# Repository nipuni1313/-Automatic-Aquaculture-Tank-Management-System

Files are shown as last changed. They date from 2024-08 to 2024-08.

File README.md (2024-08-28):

# Automated Aquaculture Tank Monitoring System

**Department of Electronic & Telecommunication Engineering, University of Moratuwa, Sri Lanka**  
**Authors:**  
H. M. G. N. I. Herath - 210216F  
H. M. V. Vidumini - 210669U  
**Module:** EN 2160 Electronic Design Realization  
**Submission Date:** 21st July 2024

## Overview

The Automated Aquaculture Tank Monitoring System is designed to provide real-time monitoring and management of crucial parameters in aquaculture environments. The system tracks pH levels, temperature, and total dissolved solids (TDS) in fish tanks and pools, ensuring optimal conditions for fish health and growth. Additionally, it features an integrated feeder system to automate the feeding process.

This project aims to contribute to the sustainability and efficiency of the aquaculture industry by offering a comprehensive solution that enhances productivity, improves operational efficiency, and safeguards fish health.

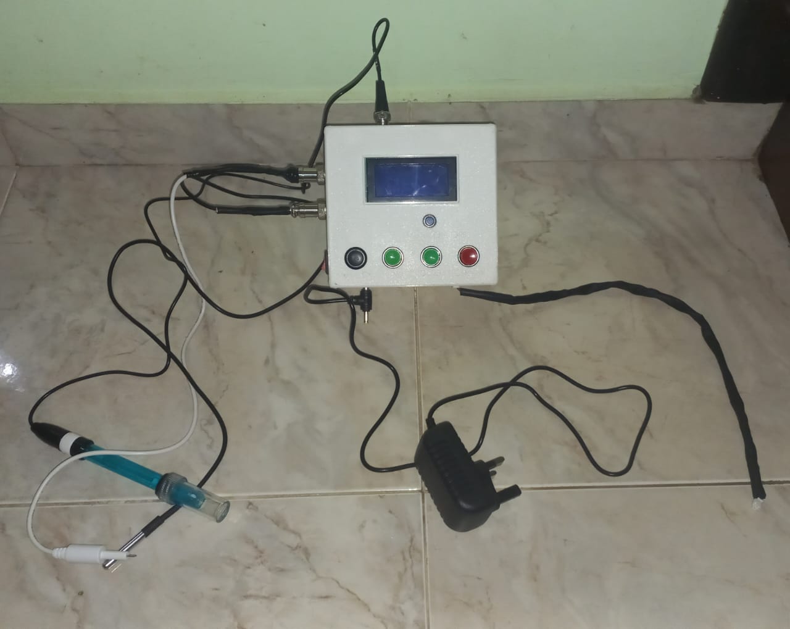
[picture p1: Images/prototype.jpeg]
Prototype of the user interface

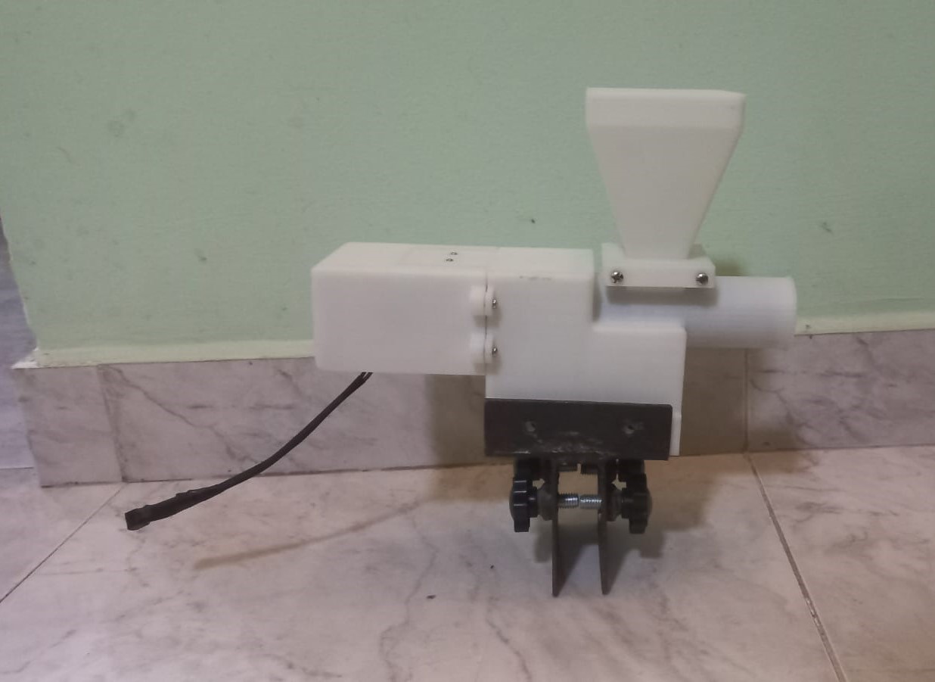
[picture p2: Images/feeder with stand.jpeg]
Prototype of the feeder


## Table of Contents

1. [General Specifications](#general-specifications)
2. [Project Objectives](#project-objectives)
3. [System Components](#system-components)
4. [Hardware Requirements](#hardware-requirements)
5. [Software Requirements](#software-requirements)
6. [Installation and Setup](#installation-and-setup)
7. [Usage](#usage)
8. [Contributing](#contributing)
9. [Acknowledgements](#acknowledgements)

## General Specifications

The project follows the Cambridge EDC model, which is structured into three main phases:

- **Explore:** Examination of existing products and stakeholder engagement to gather insights.
- **Create:** Development of conceptual designs based on identified needs.
- **Evaluate:** Assessment and refinement of designs to ensure they meet objectives and improve upon current market offerings.

## Project Objectives

- **Ensure Fish Health:** Continuous monitoring of pH, temperature, and TDS levels to maintain optimal conditions for fish well-being.
- **Improve Efficiency:** Automate monitoring and feeding processes to reduce labor and improve operational efficiency.
- **Enhance Productivity:** Provide actionable insights for optimizing farm management practices.

## System Components

The system comprises several key components:

- **Sensors:** For monitoring pH levels, temperature, and TDS.
- **Control Unit:** Manages data from sensors and controls the feeder.
- **Feeder System:** Automatically dispenses feed based on predefined schedules.
- **User Interface:** Displays real-time data and allows user interaction.

## Hardware Requirements

- Microcontroller (e.g., ATmega328P)
- pH sensor
- Temperature sensor
- TDS sensor
- LCD Display (with I2C module)
- DC Motor (for feeder system)
- Real-Time Clock (RTC) module (e.g., DS1302)
- Buzzer
- Additional connectors, resistors, capacitors, and other electronic components

## Software Requirements

- Arduino IDE for microcontroller programming
- Relevant libraries for sensor integration (e.g., LiquidCrystal_I2C for LCD, RTClib for RTC)
- Python or another language for data analysis (if needed)

## Installation and Setup

**Hardware Setup:**

- Assemble the hardware components according to the schematic diagrams provided in the project documentation.
- Connect the sensors to the microcontroller using appropriate connectors.

**Software Setup:**

- Download and install the Arduino IDE.
- Install necessary libraries (LiquidCrystal_I2C, RTClib, etc.).
- Upload the provided code to the microcontroller using the Arduino IDE.

## Usage

- Once the system is powered on, it will automatically begin monitoring the tank conditions.
- Real-time data will be displayed on the LCD screen.
- Alerts will be triggered if any parameter exceeds the predefined threshold.
- The feeder system can be scheduled to dispense feed automatically at set intervals.

## Contributing

Contributions are welcome! Please feel free to submit a pull request or open an issue to discuss any changes or improvements.

## Acknowledgements

We would like to acknowledge the support of the Department of Electronic & Telecommunication Engineering, University of Moratuwa, Sri Lanka.

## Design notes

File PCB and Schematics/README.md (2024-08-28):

This contains all the dacuments related to the PCB and its schematics.

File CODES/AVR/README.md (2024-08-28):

# AVR Code for Aqua Culture Fish Feeder System

This directory contains the AVR code for the Aqua Culture Fish Feeder System, which monitors and controls environmental parameters in an aquaculture tank using an ATmega328P microcontroller. The code includes functionality for an LCD display, sensor readings for temperature, pH, and TDS (Total Dissolved Solids), motor control for fish feeding, and a button-based menu system.

## Features

- **LCD Display Control**: Utilizes an I2C 16x2 LCD to display sensor readings and system status.
- **Temperature Sensing**: Interfaces with a DS18B20 sensor to monitor water temperature.
- **TDS and pH Monitoring**: Reads and displays water quality using analog TDS and pH sensors.
- **Motor Control**: Operates a feeding motor based on user settings and schedules.
- **User Interface**: Provides a simple button-driven menu for setting parameters and manual control.

## File Overview

- **main.c**: The main application code that initializes all peripherals and manages the main program loop.
- **Functions for LCD**: Functions and definitions for controlling the I2C LCD display.
- **ds18b20**: Functions for interfacing with the DS18B20 temperature sensor.
- **tds & pH**: Code for reading TDS and pH sensor values.
- **motor control**: Functions for controlling the feeding motor.
- **menu**: Implements the user interface for navigating the menu and setting parameters.

## Installation

To compile and upload the AVR code to the ATmega328P microcontroller:

1. **Clone this repository**:
    ```bash
    git clone https://github.com/yourusername/aqua-culture-fish-feeder.git
    cd aqua-culture-fish-feeder/avr_code
    ```

2. **Open in AVR Development Environment**:
   - You can use Atmel Studio, Arduino IDE, or any AVR-compatible IDE.
   
3. **Compile the Code**:
   - Ensure all necessary libraries and header files are included.
   - Set the microcontroller to ATmega328P and the correct clock speed (e.g., 16 MHz).

4. **Upload the Code**:
   - Connect your ATmega328P microcontroller to your computer via an AVR programmer or Arduino board.
   - Upload the compiled code to the microcontroller.

## Usage

1. **Power on the system** and observe the initialization messages on the LCD display.
2. **Navigate the menu** using the connected buttons to configure settings such as feeding times and sensor thresholds.
3. **Monitor the sensors**: Temperature, pH, and TDS readings will be continuously displayed on the LCD.
4. **Control the motor**: Use the menu to manually activate the feeding motor or set automated feeding schedules.

## Contributing

Feel free to contribute to the project by forking the repository, making changes, and submitting a pull request. For significant changes, please open an issue first to discuss your ideas.

## License

This code is open-source and available under the MIT License. See the [LICENSE](LICENSE) file for more information.

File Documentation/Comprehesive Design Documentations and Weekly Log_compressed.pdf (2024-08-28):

## Department of Electronic & Telecommunication Engineering, University

of Moratuwa, Sri Lanka.

# Automated Aquaculture Tank Monitoring System Design Documentation

H. M. G. N. I. Herath | 210216F
H. M. V. Vidumini | 210669U

## Submitted in partial fulfillment of the requirements for the module EN 2160 Electronic Design Realization

21st July 2024

## Contents

1 Comprehensive Design Details | 3
1.8.2 | Final Artwork Drawings
2 Appendix A : Weekly Log Entries | 107

EN 2160 Electronics Design Realization

2.5 4 March - 10 March 2024 | 108
2.6 11 March - 17 March 2024 | 109
2.7 18 March - 24 March 2024 | 110
2.8 25 March - 31 March 2024 | 111
2.9 1 April - 7 April 2024 | 113
2.10 15 April - 21 April 2024 | 116
2.11 22 April - 28 April 2024 | 118
2.12 29 April - 5 May 2024 | 118
2.13 6 May - 12 May 2024 | 120
2.14 6 May - 12 May 2024 | 121
2.15 June 21 - June 27 2024 | 122
2.16 June 28- July 6 2024 | 122
2.17 July 16 - July 22 2024 | 123
3 Appendix B : Previously Used Arduino Code | 124

## 1 Comprehensive Design Details

### 1.1 Introduction

This report presents a comprehensive analysis and design documentation for an advanced aquaculture monitoring and feeding system. The system integrates various sensors and electronic components to ensure optimal water quality and automate feeding processes in aquaculture environments. The aim is to provide a reliable, durable, and user-friendly solution that enhances the efficiency and effectiveness of fish tank management.

### 1.2 Project overview

Our project involves the design and development of an advanced aquaculture monitoring and feeding system. The system is engineered to provide real-time monitoring of crucial water parameters and automate the feeding process in fish tanks, thereby enhancing the efficiency and health management of aquaculture environments.

### 1.3 The primary objectives of the aquaculture tank monitoring device

The primary objectives of the device are:

- Real-time Monitoring: Provide continuous and accurate monitoring of pH, Total Dissolved Solids (TDS), and water temperature in fish tanks.
- Alert System: Notify users promptly through alarms and warning messages when monitored parameters fall outside specified ranges.
- User Interface: Offer an intuitive interface with LCD display and pushbuttons for easy navigation and parameter adjustment.
- Feeding Automation: Automate fish feeding schedules based on user-defined times or allow manual feeding control through the interface.
- Durability and Reliability: Ensure robust construction using materials like ABS plastic and metal stands to withstand aquatic environments.
- Ease of Installation: Facilitate simple installation on tank rims using hooks and adjustable screws, ensuring stability and optimal sensor placement.
- Enhanced Aquaculture Management: Support efficient and effective management of fish tanks to promote healthier aquatic environments and growth.

These objectives aim to enhance user experience, streamline aquarium maintenance, and contribute to the overall well-being of aquatic life through advanced monitoring and feeding automation capabilities.

### 1.4 Sensor Specifications

In our aquaculture tank monitoring system, accurate and reliable data collection is critical for maintaining optimal water quality conditions. The system uses 3 sensors to monitor the key parameters
- pH
- Total Dissolved Solids (TDS)
- water temperature

This section provides detailed specifications of the sensors integrated into the system. Each sensor is chosen for its precision, reliability, and suitability for continuous monitoring in an aquaculture environment.

### 1.4.1 pH Sensor

The pH level of water is a crucial parameter in aquaculture as it directly affects the health and growth of aquatic organisms. Maintaining an optimal pH range is essential for ensuring the metabolic processes of fish and other aquatic life are functioning properly. Deviations from the ideal pH range can lead to stress, disease, and even mortality. Therefore, monitoring pH levels continuously helps in maintaining a stable and healthy environment, improving the overall productivity and sustainability of the aquaculture operation.
The chosen sensor and its specifications are as follows:

Figure 1: pH Sensor E-201-C

Model: pH Sensor E-201-C
- Measurement Range: 0 - 14 pH
- Accuracy: ±0.01 pH
- Resolution: 0.01 pH
- Operating Temperature: 0°C to 50°C
- Response Time: ¡= 10 seconds for 95% of final value
- Output Type: Analog Voltage
- Supply Voltage: 3.3V to 5V
- Calibration: Two-point (4.0, 7.0, and 10.0 pH)
- Connector: BNC connector for pH probe

### 1.4.2 TDS Sensor

Total Dissolved Solids (TDS) measure the combined content of all inorganic and organic substances contained in a liquid, which are present in a molecular, ionized, or micro-granular suspended form. In aquaculture, maintaining appropriate TDS levels is essential for the health of aquatic organisms as it affects water hardness, salinity, and the overall ionic balance. High TDS levels can indicate poor water quality and the presence of harmful substances, whereas low levels can lead to nutrient deficiencies. Continuous monitoring of TDS helps in maintaining optimal water quality and preventing potential health issues in the aquaculture environment.
The chosen sensor and its specifications are as follows:

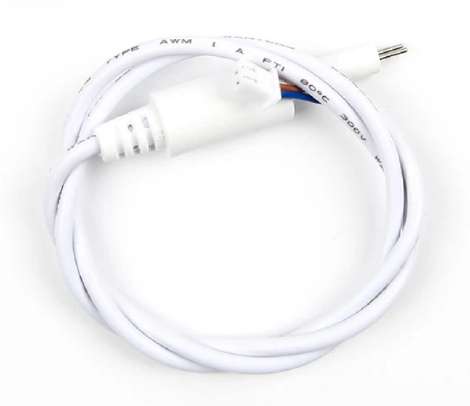
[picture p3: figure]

Figure 2: Gravity TDS Meter V1.0

Model: Gravity TDS Meter V1.0

- Measurement Range: 0 - 1000 ppm
- Accuracy: ±10% full scale
- Resolution: 1 ppm
- Operating Temperature: 0°C to 40°C
- Response Time: 10 seconds
- Output Type: Analog Voltage
- Supply Voltage: 3.3V to 5V
- Calibration: One-point (700 ppm)
- Connector: 3-pin JST connector

### 1.4.3 Water Temperature Sensor

Water temperature is a critical factor in aquaculture as it influences the metabolic rates, growth, and reproductive cycles of aquatic organisms. Each species has a preferred temperature range, and deviations from this range can cause stress, reduce immune response, and impact overall health. Additionally, temperature affects the solubility of oxygen and the efficacy of other water quality parameters. Continuous temperature monitoring allows for the maintenance of optimal conditions, ensuring a healthy and productive aquaculture environment.
The chosen sensor and its specifications are as follows:

Figure 3: DS18B20 Digital Thermometer

Model: DS18B20 Digital Thermometer

- Measurement Range: -55°C to +125°C
- Accuracy: ±0.5°C (from -10°C to +85°C)
- Resolution: Programmable 9 to 12 bits
- Response Time: ¡= 750 milliseconds
- Output Type: Digital (1-Wire Protocol)
- Supply Voltage: 3.0V to 5.5V
- Connector: 3-pin (VCC, GND, Data)

### 1.5 Microcontroller specifications

The Atmel® picoPower® ATmega328P microcontroller is an excellent choice for this project due to its low-power CMOS architecture and high performance. This 8-bit microcontroller, based on the AVR® enhanced RISC architecture, executes powerful instructions in a single clock cycle, achieving throughputs close to 1MIPS per MHz. This allows for optimization between power consumption and processing speed, making it ideal for sensor applications.
The below is a summary of key features which are extracted from ATMega328P datasheet. (https://ww1.microchip.com/downloads/en/DeviceDoc/Atmel-7810-Automotive-Microcontrollers-ATmega328P_Datasheet.pdf)

Key Features

- Advanced RISC Architecture:

– 131 powerful instructions, mostly single clock cycle execution.

– Up to 20 MIPS throughput at 20MHz.

- Memory:

– 32KB In-System Self-Programmable Flash memory.

– 1KB EEPROM.

– 2KB SRAM.

- Peripheral Features:

– 8-channel 10-bit ADC.

– Six PWM channels.
– Two 8-bit Timer/Counters and one 16-bit Timer/Counter.

– Master/Slave SPI Serial Interface.

– I2C compatible 2-wire Serial Interface.

- Power Consumption:

– Active Mode: 0.2mA at 1MHz, 1.8V.

– Power-down Mode: 0.1µA.
– Power-save Mode: 0.75µA (including 32kHz RTC).
- Operating Voltage:

– 1.8 - 5.5V.

- Operating Temperature Range:

– -40°C to 105°C.

### 1.6 Circuit Analysis for Electronic Sub-Assemblies

The electronic design for our comprehensive monitoring and management system consists of 7 main electronic sub-assemblies. These sub-assemblies work together to monitor and maintain optimal conditions in fish tanks and pools used in both ornamental fish breeding and fish farming for human consumption. The sub-assemblies include,

1. Power Regulator
2. Microcontroller Unit
3. pH Sensor Module and Interface
4. Water Temperature Sensor Module and Interface
5. TDS Sensor Module and Interface
6. User Interface
7. Motor Drive and Switch

Each sub-assembly plays a critical role in ensuring the system’s functionality and reliability. This document provides detailed descriptions of each sub-assembly, including their specifications, components, and functionality within the system.

### 1.6.1 Power Regulator

The power regulator converts the input voltage from 12V to a stable 5V using the LM7805CT power regulator.

Figure 4: Voltage Regulator Circuit

Components and Sections

1. Power Input: The 12V DC input is connected to the circuit via the input connector J1.
2. Input Filtering: Capacitor C1, connected across the input voltage, filters out any noise or spikes from the input power supply. This ensures that the voltage regulator receives a clean 12V DC input.
3. Voltage Regulation: The LM7805CT voltage regulator receives the filtered 12V input at its IN pin (Pin 1). It regulates this input down to a stable 5V DC, which is provided at its OUT pin (Pin 3). The ground pin (Pin 2) is connected to the common ground of the circuit.

4. Output Filtering: Capacitor C2, connected across the output voltage, smooths out any residual noise or ripple in the 5V output, providing a clean and stable 5V DC to the load.

In summary, the power regulator sub-assembly is designed to take a 12V DC input and provide a stable 5V DC output using an LM7805CT voltage regulator. The capacitors (C1 and C2) are crucial for filtering and stabilizing the input and output voltages, respectively. Therefore, this ensures that all components in the system receive a consistent and reliable power supply, which is essential for their optimal operation. The microcontroller unit serves as the brain of the system, orchestrating various tasks through its sub-units: power supply filtering, oscillator circuit, in-system programming, reset circuit, and peripheral I/O connections. Each sub-unit plays a critical role in ensuring the functionality and stability of the system.

### 1.6.2 Microcontroller Unit

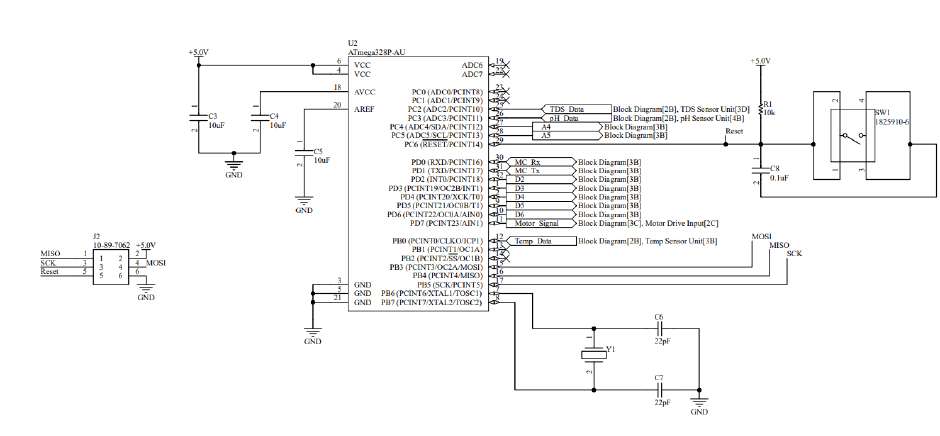
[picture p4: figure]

Figure 5: Microcontroller Unit Circuit

1. Power Supply Filtering
- Components: C3, C4, C5 (10µF Capacitors)
- Function: These capacitors filter the 5V power supply to provide a stable voltage to the microcontroller and other connected components, minimizing voltage fluctuations and noise.

Components and Sections

2. In-System Programming (ISP)
- Component: J2 (Programming Header)
- Function: This header is used for programming the microcontroller via ISP, allowing firmware updates and debugging without removing the microcontroller from the circuit.
3. Oscillator Circuit
- Components: Y1 (Crystal Oscillator), C6, C7 (22pF Capacitors)
- Function: The crystal oscillator (Y1) provides the clock signal necessary for the microcontroller’s operations. The capacitors (C6 and C7) stabilize the oscillations of the crystal, ensuring accurate and reliable timing.
4. Reset Circuit
- Components: R1 (10k Resistor), C8 (0.1µF Capacitor), SW1 (Reset Switch)
- Function:

– R1: The pull-up resistor keeps the reset pin high under normal conditions.
– C8: The capacitor debounces the reset switch to prevent false triggering.
– SW1: The reset switch allows for manually resetting the microcontroller, reinitializing the system as needed.
5. Peripheral Connections
- Analog and Digital I/O Pins:

– ADC6, ADC7 (Pins 18, 20): Used for receiving data from the TDS and pH sensors. – Digital Pins (PC0 - PC6, PD0 - PD7, PB0 - PB7): Connected to various sensors, the motor driver, and user interface elements, facilitating communication and control.

- Serial Communication Pins:

– TX, RX (PD0, PD1): These pins are designated for serial communication, enabling data exchange with other devices.
– SPI (PB3 - PB5): These pins are used for in-system programming and communication with other SPI devices, supporting data transfer and device interfacing.

The microcontroller unit is integral to the system’s operation, coordinating tasks through wellstructured sub-units. These include power supply filtering for voltage stability, an oscillator circuit for precise timing, ISP for easy programming, a reset circuit for system reinitialization, and various peripheral connections for interfacing with sensors and other components.

### 1.6.3 pH Sensor Module and Interface

The pH sensor module interfaces with the pH sensor to obtain pH readings, process the signal, and transmit it to the microcontroller. This module includes operational amplifiers (op-amps), voltage references, and other necessary components for measuring and processing pH levels from a pH sensor.

Figure 6: pH sensor module

Components and Functions

1. pH Sensor Input
- Function: Connects the pH sensor to the module, allowing the analog signal proportional to the pH level to be processed.
- Component: Connector (J7)
2. Signal Conditioning
- Function: Buffers and stabilizes the pH signal from the sensor to isolate it from the rest of the circuit.
- Components:

– Op-Amp: U4A (TLC4502IDR) – Resistors: R14, R15, R16
– Capacitors: C13, C14, C15
3. Signal Amplification
- Function: Amplifies the buffered pH signal to a level suitable for further processing.
- Components:

– Op-Amp: U3B (LM358DR)
– Resistors: R17, R18
– Capacitors: C16, C17
4. Voltage Reference
- Function: Provides a stable reference voltage for the op-amps to ensure accurate measurements.

- Components:

– Voltage Reference: U1 (TL431ACZ-AP) – Resistors: R19, R20
– Capacitors: C18, C19
5. Output Signal Conditioning
- Function: Further conditions the amplified signal, making it suitable for the ADC in the microcontroller.
- Components:

– Op-Amp: U5A (LM358DR)
– Resistors: R22, R23, R24 – Capacitors: C19
– Diodes: D1, D2
6. Temperature Compensation
- Function: Compensates the pH signal for temperature variations to ensure accuracy across different temperatures.
- Components:

– Thermistor: TH1 (NTCLE100E3104JB0)
– Op-Amp: U3A (LM358DR)
– Resistors: R21, R22, R23, R24
– Capacitors: C19
7. Backup Connector
- Function: Provides the conditioned pH signal to the microcontroller for further processing and analysis.
- Components:

– Connector: J2
– Op-Amp: U5B (LM358DR)

This pH sensor module is designed to interface a pH sensor with a microcontroller. It conditions the analog signal from the pH sensor, amplifies it, compensates for temperature variations, and provides a stable, noise-free output signal to the microcontroller. The use of op-amps, voltage references, and passive components ensures accurate and reliable pH measurements.

### 1.6.4 Water Temperature Sensor Module and Interface

The digital water temperature connected to the device operates using the sub-assembly given below.

Figure 7: Water Temperature Sensor Module

Functionality: This module interfaces a temperature sensor with a microcontroller, providing the necessary power and signal conditioning to ensure accurate temperature data is communicated to the microcontroller.
Components:

- Connector: J9 - B3B-XH-AM(LF)(SN)(P)
- Pull-up Resistor: R47
- Temperature Data Line: Temp Data

### 1.6.5 TDS Sensor Module and Interface

Figure 8: TDS Sensor module

TDS Sensor Module and Interface provides an interface to the TDS sensor to connect with the microcontroller. It includes various operational amplifiers (op-amps), voltage regulators, and other components necessary for measuring and processing TDS levels from a TDS sensor.

Components and Sections

1. Power Supply
Functionality: Provides stable voltage supply to various parts of the circuit.

Components:

- Voltage Regulators:

– AMS1117-3.3 (U8): Regulates the input 5V to a stable 3.3V output.
– TPS60400DBVR (U9): Provides a negative voltage (-3V) from a positive 3.3V input.
- Capacitors:

– C28, C29, C30: Decoupling capacitors for U8.
– C31, C32, C33, C34, C35, C36, C37: Charge pumping and output stabilization capacitors for U9.
2. TDS Sensor Input
Functionality: Receives the input signal from the TDS sensor. Components:
- Connectors

– J8: Primary input for the TDS sensor.
– J21: Secondary connection point, for calibration of the sensor and backup purposes.
3. Signal Conditioning

Functionality: Buffers and amplifies the input signal from the TDS sensor.

Components:

- Op-Amp (U6A - LMV324IDR): Buffers and amplifies the TDS sensor signal.
- Resistors:

– R39, R40, R41, R42: Set gain and biasing for U6A.
- Capacitors:

– C20, C21, C22, C23: Decoupling and noise reduction.
- Voltage Reference (U7 - CJ4006DM): Provides a stable reference voltage.
- Resistors:

– R43, R44, R45, R46: Set output voltage for U7.
- Capacitors:

– C24, C25, C26, C27: Stabilize the reference voltage.

4. Signal Amplification

Functionality: Further amplifies and conditions the TDS signal.

Components:

- Op-Amps (U6B, U6C, U6D - LMV324DR): Amplify and condition the TDS signal.
- Resistors:

– R34, R35, R36, R37, R38, R47, R48, R49, R50: Set gain and biasing for amplification stages.
- Capacitors:

– C19, C38, C39, C40, C41, C42, C43, C44: Filtering and decoupling.
- Diodes:

– D1, D2, D3, D4, D5, D6: Protect op-amps from voltage spikes.

5. Output Signal Conditioning

Functionality: Buffers the final TDS signal before sending it to the microcontroller.

Components:

- Op-Amp (U6D - LMV324DR): Buffers the final TDS signal.
- Resistors:

– R60, R61: Set output level and feedback.
- Capacitor:

– C25: Stabilizes the output signal.

6. Output to Microcontroller

Functionality: Provides the conditioned TDS signal to the microcontroller for further processing.

Components:

- Connector (J21): Delivers the TDS Data signal to the microcontroller.

This circuit is designed to interface a TDS sensor with a microcontroller. It conditions the analog signal from the TDS sensor, amplifies it, and provides a stable, noise-free output signal to the microcontroller. The use of op-amps, voltage regulators, and passive components ensures accurate and reliable TDS measurements. The negative voltage generator and multiple stages of amplification and filtering are crucial for achieving high precision in TDS readings.

### 1.6.6 User Interface

The user interface circuit interfaces the buttons, display, and the WiFi module to the microcontroller, allowing for user interaction and connectivity. It includes connectors and necessary components for stable and reliable operation.

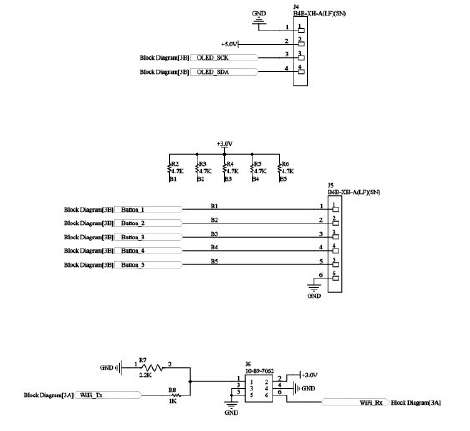
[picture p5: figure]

Figure 9: User Interface

Functionality and Components

1. Display: The display module connects through the J4 connector, allowing the microcontroller to send data and commands for visual output.
- Connector (J4):

– Provides the interface for the display module to connect to the circuit.
– Ensures proper data and power connections between the microcontroller and the display.
2. Buttons Panel: The buttons connect through the J5 connector. When a button is pressed, the corresponding input signal changes state, which is detected by the microcontroller.
The pull-up resistors (R2, R3, R4, R5, R6) ensure stable input signals and reduce noise.
- Connector (J5):

– Provides the interface for the buttons panel to connect to the circuit.
- Resistors (R2, R3, R4, R5, R6):

– Pull-up resistors ensure that each button input is at a known voltage level when not pressed.
– Provides debounce functionality to avoid multiple triggers from a single button press.
3. WiFi Module Interface: The WiFi module connects through the J6 connector, enabling wireless communication.
Resistor R7 ensures the signals between the microcontroller and the WiFi module are stable and within proper voltage levels.
- Connector (J6):

– Provides the interface for the WiFi module to connect to the circuit.
- Resistor (R7):

– Ensures the proper biasing and signal integrity for the WiFi module interface.

Additionally, it should be mentioned that the buzzer for the alarm system which is also a part of the user interface is to be connected to pin 12, after the microcontroller is programmed.

This user interface circuit facilitates the interaction between the user and the system via buttons and display, and enables wireless communication through the WiFi module. The use of connectors and resistors ensures stable and reliable connections and signal integrity.

### 1.6.7 Motor Drive and Switch

The motor driver part controlls the motor mechanism and provides and interface to the motor in the feeder.

Figure 10: Motor Drive and switch

Components and Connections

1. MOSFET (Q1 - IRF540N):
- Function: Acts as a switch to control the motor. The gate of the MOSFET receives the control signal (Motor Signal), which determines whether the MOSFET is on or off.
- Gate Resistor (R48 - 100 ohms): Limits the inrush current to the gate to protect the MOSFET and control the switching speed.
- Pull-down Resistor (R49 - 10k ohms): Ensures that the MOSFET stays off when there is no input signal, preventing accidental activation.
2. Diode (D9 - 1N5819):
- Function: Provides a path for the current when the motor is turned off, protecting the MOSFET from voltage spikes caused by the inductive load (motor).
- Protection: Ensures the longevity of the MOSFET by preventing back EMF from damaging it.
3. Connector (J10):
- Function: Connects the motor to the circuit.
- Pin 1: Connected to the drain of the MOSFET.
- Pin 2: Connected to the +12V supply.
4. Capacitor (C38 - 100uF):
- Function: Provides decoupling and helps to smooth out voltage fluctuations and noise from the power supply.
- Stabilization: Ensures stable operation of the motor by reducing voltage spikes and ripples.

5. Control Signal (Motor Signal):
- Source: Comes from the microcontroller unit (MCU) and is applied to the gate of the MOSFET through the gate resistor.
- Function: Determines the on/off state of the MOSFET, thereby controlling the motor.

Operation

- When Motor Signal is High:

– The gate of the MOSFET (Q1) receives a high signal, turning the MOSFET on.

– Current flows from the +12V supply through the motor (connected to J10), the MOSFET, and to ground, powering the motor.

- When Motor Signal is Low:

– The gate of the MOSFET (Q1) receives a low signal, turning the MOSFET off.

– No current flows through the motor, thus turning it off.

- Protection Mechanism:

– The diode (D9) protects against voltage spikes by providing a path for the inductive kickback current.
– The capacitor (C38) stabilizes the supply voltage, ensuring smooth operation of the motor.

In conclusion, this motor drive circuit utilizes a MOSFET (IRF540N) to control a motor using a digital signal (Motor Signal) from a microcontroller. The design includes protective components such as a diode to prevent voltage spikes and a capacitor to smooth power supply fluctuations. This simple yet effective circuit ensures reliable motor control and protection of the components.

### 1.7 PCB Specifications

### 1.7.1 Trace Width Calculations

Trace width is a crucial parameter in PCB design, influencing the board’s electrical performance and thermal management. Proper trace width ensures that the traces can handle the expected current without excessive heating or voltage drop, thereby maintaining the reliability and functionality of the PCB.

Calculation Methodology:

The trace width for different nets in a PCB is calculated based on the maximum current the trace needs to carry, the permissible temperature rise, and the PCB material properties. The IPC-2221 standard provides guidelines for determining the appropriate trace width for given current and temperature rise requirements.

The formula used for calculating the trace width is derived from the IPC-2221 standards:

W =

I
k · (Tr)

0.44 · (A)

0.725

where:
- W is the trace width (in mils)
- I is the current (in amperes)
- k is a constant (0.024 for external layers, 0.048 for internal layers)
- Tr is the temperature rise (in °C)
- A is the cross-sectional area (in mils²
)

Design Requirements:

The calculations are done using these assumptions and facts:

- Ambient Temperature: 25°C
- Temperature Rise: 10°C
- Copper Thickness: 1 oz/ft²

The PCB design includes the following trace widths for different nets:

1. 55 mil for Powering the Motor
2. 15 mil for Power Traces
3. 10 mil for Signal Traces

Calculations:

1. 55 mil for Powering the Motor Considering
- a maximum trace length: 4000mil
- maximum current: 1.5A

Calculated trace width:

- maximum: 53 mil
- minimum: 18 mil

Therefore trace width of 55 mil is chosen considering other possibilities as well.

2. 15 mil for Power Traces Considering
- a maximum trace length: 9000 mil
- maximum current: 200 mA

Calculated trace width:

- maximum: 3.5 mil
- minimum: 1.5 mil

Therefore trace width of 15 mil is chosen considering other possibilities as well.

3. 10 mil for Signal Traces Considering
- a maximum trace length: 10 000 mil
- maximum current: 50 mA

Calculated trace width:

- maximum: 0.2 mil
- minimum: 0.5 mil

Therefore trace width of 10 mil is chosen considering other possibilities as well.

Using larger trace widths than strictly required by the calculated values offers several advantages in PCB design.

- Firstly, it enhances reliability by reducing resistance and thereby minimizing voltage drops, especially crucial for high-current paths like power lines to motors or critical components.
- Secondly, larger traces can handle higher currents safely without excessive heating, which extends the lifespan of the PCB and reduces the risk of thermal damage.
- Additionally, during manufacturing and assembly processes, having slightly oversized traces can simplify production by reducing the sensitivity to slight variations in fabrication tolerances or soldering quality.

Overall, while there may be a marginal increase in material cost or PCB size, the benefits in terms of reliability, longevity, and ease of manufacturing often justify using larger trace widths when feasible in electronic designs.

### 1.7.2 Power Calculations

We refered to data sheets and identified the below voltage and current requirements

- pH Sensor:

– Current drawn: 20mA

– Voltage: 5V

- Digital Temperature Sensor:

– Current drawn: 6mA

– Voltage: 5V

- TDS Sensor:

– Current drawn: 6mA

– Voltage: 5V

- Microcontroller:

– Active mode: 1.5mA

– Sleep mode: 1uA

- Wi-Fi Module:

– Active mode: 200mA

– Voltage: 3.3V

- LCD Display:

– Current drawn: 1.65mA

– Voltage: 5V

- Buzzer:

– Current drawn: 10mA

– Voltage: 5V

- DC Motor:

– Current drawn: 300mA

– Voltage: 12V

After reviewing the current requirements for each component in our system, the trace width calculations were conducted to ensure robust PCB design. The highest current draw identified was from the DC Motor at approximately 300mA. Considering a safety margin, the trace width was calculated for 450mA to account for variations and ensure reliability. Using the IPC-2221 standard and assuming 1oz copper thickness, the calculated trace width for the DC Motor was approximately 6.81 mils (0.173 mm), rounded to the nearest standard practice of 10 mils (0.254 mm) for power lines. This approach ensures adequate current carrying capacity and supports the overall reliability of the PCB design for our aquaculture monitoring system.

### 1.7.3 Design Rule Violation Report

The following table shows the design rules violation report for the PCB design. The report indicates that there are no violations, ensuring that the design adheres to all specified constraints.

Rule Violations | Count
Clearance Constraint (Gap=5mil) (All),(All) | 0
Short-Circuit Constraint (Allowed=No) (All),(All) | 0
Un-Routed Net Constraint ( (All) ) | 0
Modified Polygon (Allow modified: No), (Allow shelved: No) | 0
Width Constraint (Min=0.05mil) (Max=55mil) (Preferred=5mil) (All) | 0
Power Plane Connect Rule(Direct Con-nect )(Expansion=20mil) (Conductor Width=10mil) (Air Gap=10mil) (En-tries=4) (InPadClass(’PowerPads’)) | 0
Power Plane Connect Rule(Relief Con-nect )(Expansion=11.811mil) (Conduc-tor Width=5mil) (Air Gap=5mil) (En-tries=4) (All) | 0
Minimum Annular Ring (Mini-mum=3mil) (All) | 0
Hole Size Constraint (Min=11.811mil) (Max=248.031mil) (All) | 0
Hole To Hole Clearance (Gap=9.842mil) (All),(All) | 0
Minimum Solder Mask Sliver (Gap=0mil) (All),(All) | 0
Silk To Solder Mask (Clearance=5mil) (IsPad),(All) | 0
Silk to Silk (Clearance=0mil) (All),(All) | 0
Net Antennae (Tolerance=0mil) (All) | 0
Board Clearance Constraint (Gap=0mil) (All) | 0
Height Constraint (Min=0mil) (Max=71497.938mil) (Preferred=500mil) (All) | 0
Total | 0

Table 1: Design Rules Violation Report

### 1.8 PCB Design

The documents containing layout and artwork for the PCB are as follows:

1.8.1 3D Views
Sub Topic Number | Figure Number | Caption | Page
1 | Figure 11 | 3D view - Top Layer | 23
2 | Figure 12 | 3D view - Bottom Layer | 24

Table 2: 3D Views

### 1.8.2 Final Artwork Drawings

Sub Topic Number | Figure Number | Caption | Page
1 | Figure 13 | Top-Layer | 25
2 | Figure 14 | Bottom Layer | 26
3 | Figure 15 | Top Silkscreen Overlay | 27
4 | Figure 16 | Mechanical Drawing | 28
5 | Figure 17 | Top Designator | 29
6 | Figure 18 | Top Assembly | 30
7 | Figure 19 | Top Component Outline | 31
8 | Figure 20 | Top 3D Body | 32
9 | Figure 21 | Top Courtyard | 33
10 | Figure 22 | Top Component Centre | 34
11 | Figure 23 | Top Pad Master | 35
12 | Figure 24 | Bottom Pad Master | 36
13 | Figure 25 | Drill Drawing for Top-Bottom Layer | 37
14 | Figure 26 | Drill Guide for Top-Bottom Layer | 38

Table 3: Final Artwork Drawings

### 1.8.3 Gerber Files

Sub Topic Number | Figure Number | Caption | Page
1 | Figure 27 | Copper Signal Bottom/Top | 39
2 | Figure 28 | Legend Top | 40
4 | Figure 29 | Paste Top | 40
5 | Figure 30 | Profile | 41
7 | Figure 32 | Soldermask Top/Bottom | 42

Table 4: Gerber Files

1.8.1 3D Views

The 3D views provides a three-dimensional visualization of the bottom side of the PCB with all its components. This view allows for a thorough inspection of the bottom side, checking the placement and orientation of components, and ensuring proper clearance and fit. Like the top view, it is also valuable for confirming the design and for presentations. These are crucial for visualizing the final product before manufacturing, helping to identify any potential issues in component placement or board design.

Figure 11: 3D view - Top Layer

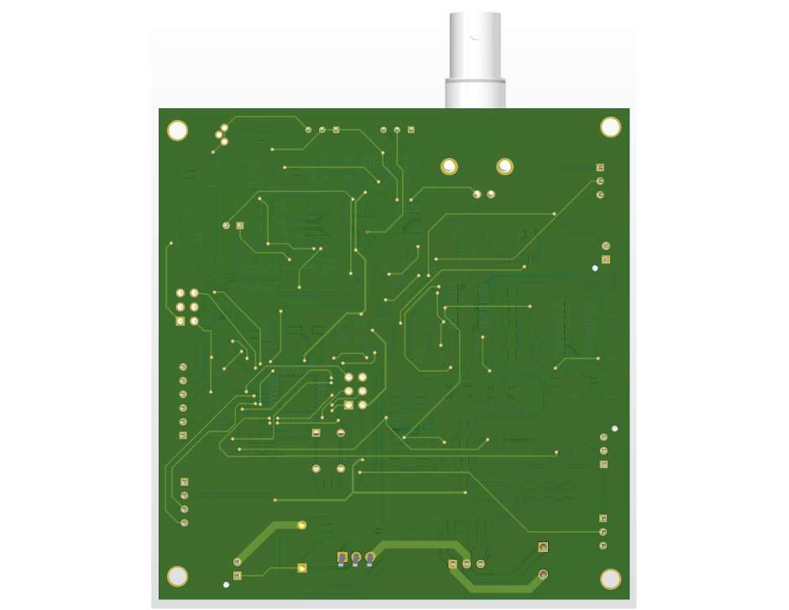
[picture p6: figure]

Figure 12: 3D view - Bottom Layer

### 1.8.2 Final Artwork Drawings

1. Top Layer

The top layer of the PCB contains the copper traces and pads on the top side of the board. It shows the electrical connections between the components placed on the top side of the PCB.

Figure 13: Top-Layer

2. Bottom Layer

The bottom layer of the PCB contains the copper traces and pads on the bottom side of the board. It shows the electrical connections between the components placed on the bottom side of the PCB.

Figure 14: Bottom Layer

3. Top Silkscreen Overlay

The top silkscreen overlay includes component outlines, reference designators, and other labels printed on the top surface of the PCB. It aids in identifying components and their placement during assembly.

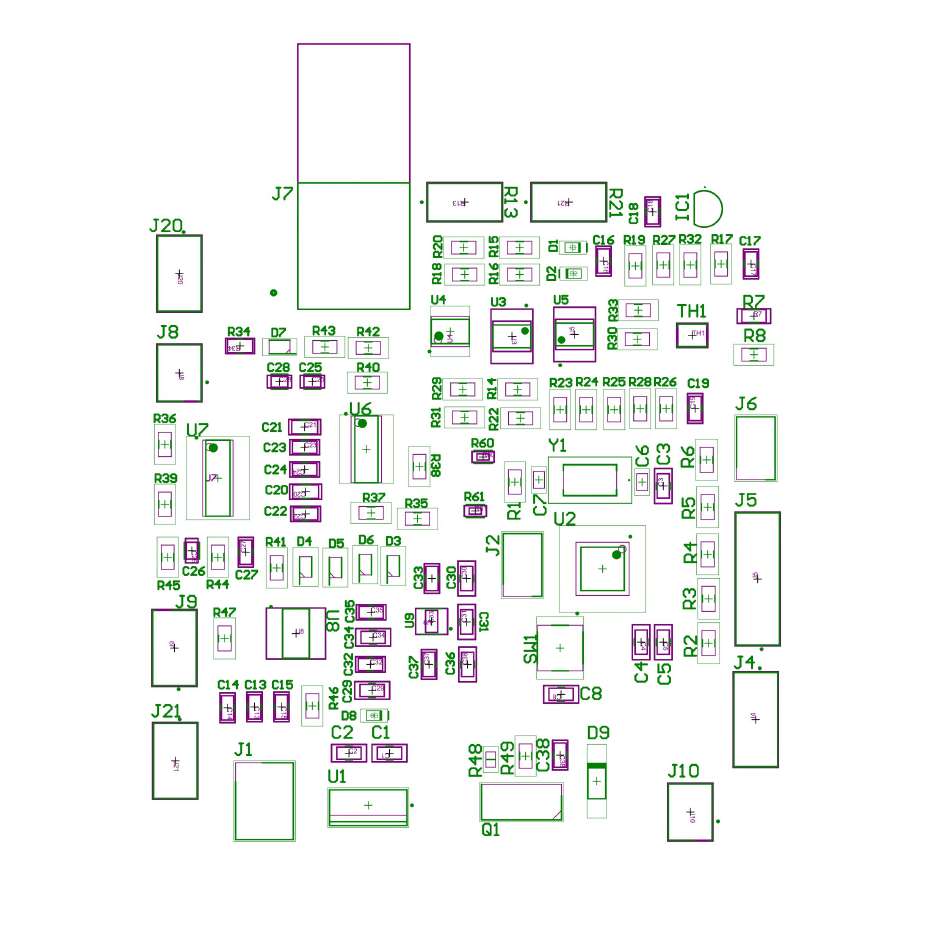
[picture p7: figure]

Figure 15: Top Silkscreen Overlay

4. Mechanical1

The mechanical layer provides detailed information about the physical dimensions and shape of the PCB. It includes board outlines, mounting holes, and any cutouts required for the PCB to fit in its enclosure.

Figure 16: Mechanical Drawing

5. Top Designator

The top designator layer displays the reference designators for all components placed on the top side of the PCB. These designators help identify each component during assembly and troubleshooting.

Figure 17: Top Designator

6. Top Assembly

The top assembly drawing shows the placement and orientation of all components on the top side of the PCB. It is used as a reference during the assembly process to ensure correct component placement.

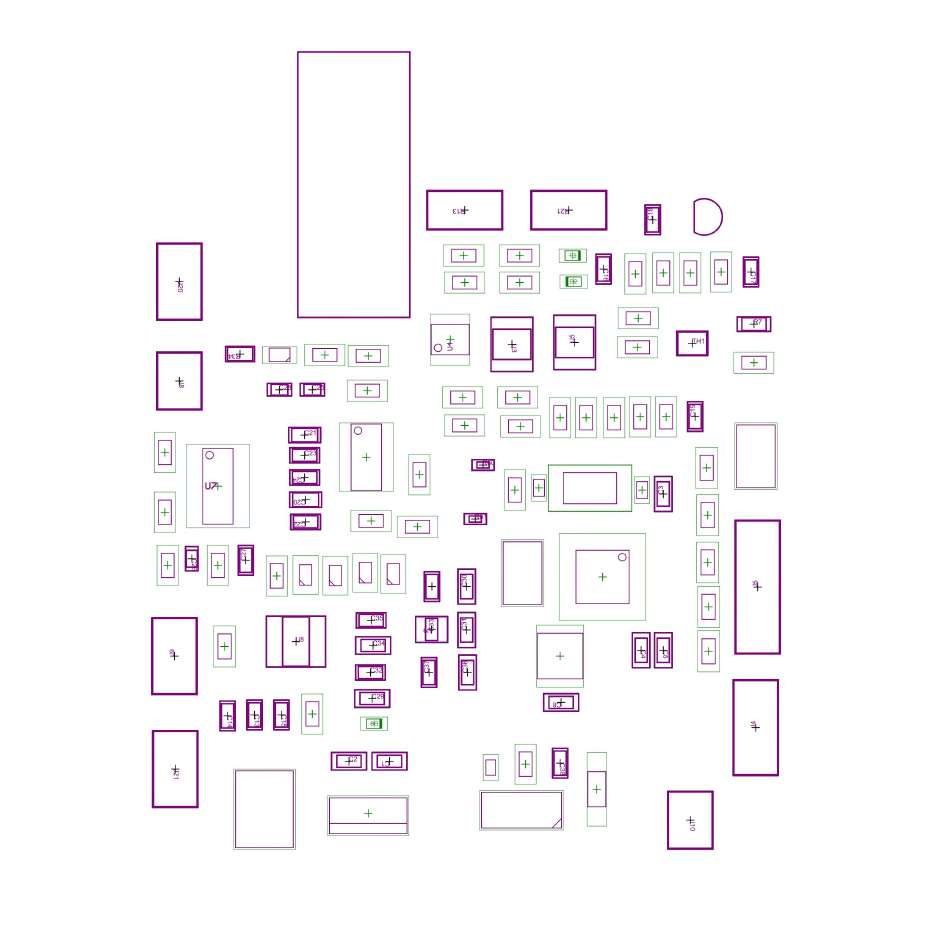
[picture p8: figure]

Figure 18: Top Assembly

7. Top Component Outline

The top component outline layer provides the exact outlines of all components placed on the top side of the PCB. It helps in verifying that all components fit properly on the board without interference.

Figure 19: Top Component Outline

8. Top 3D Body

The top 3D body layer includes three-dimensional models of all components placed on the top side of the PCB. This layer aids in visualizing the assembled PCB in 3D, ensuring proper component fit and clearance.

Figure 20: Top 3D Body

9. Top Courtyard

The top courtyard layer defines the minimum required space around each component on the top side of the PCB. This ensures there is enough clearance for manufacturing processes and to prevent components from interfering with each other.

Figure 21: Top Courtyard

10. Top Component Centre

The top component center layer marks the exact center points of all components placed on the top side of the PCB. These points are used for automated placement machines during the assembly process.

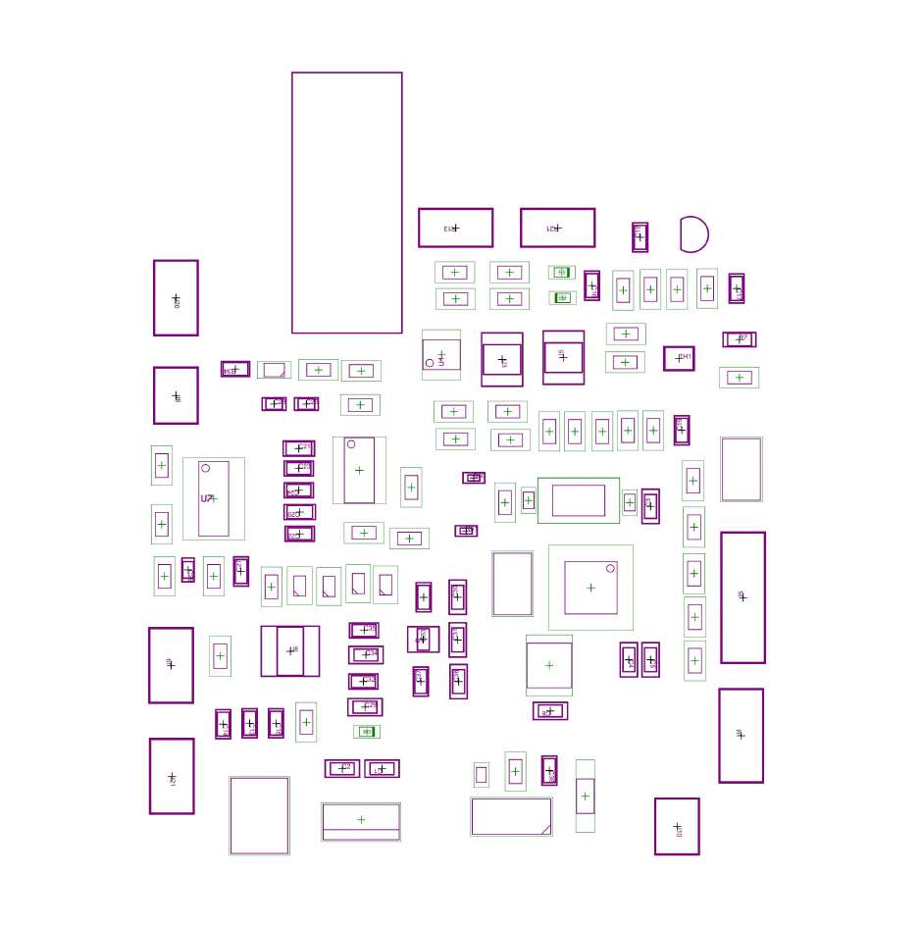
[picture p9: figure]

Figure 22: Top Component Centre

11. Top Pad Master

The top pad master layer shows all the pads (contact points) on the top side of the PCB where components will be soldered. It is used to create the solder paste stencil for the soldering process.

Figure 23: Top Pad Master

12. Bottom Pad Master

The bottom pad master layer shows all the pads (contact points) on the bottom side of the PCB where components will be soldered. It is used to create the solder paste stencil for the soldering process on the bottom side.

Figure 24: Bottom Pad Master

13. Drill Drawing for Top-Bottom Layer

The drill drawing for the top-bottom layer provides the locations and sizes of all holes to be drilled in the PCB, including vias, mounting holes, and component lead holes. It is used by the manufacturer to create the holes accurately.

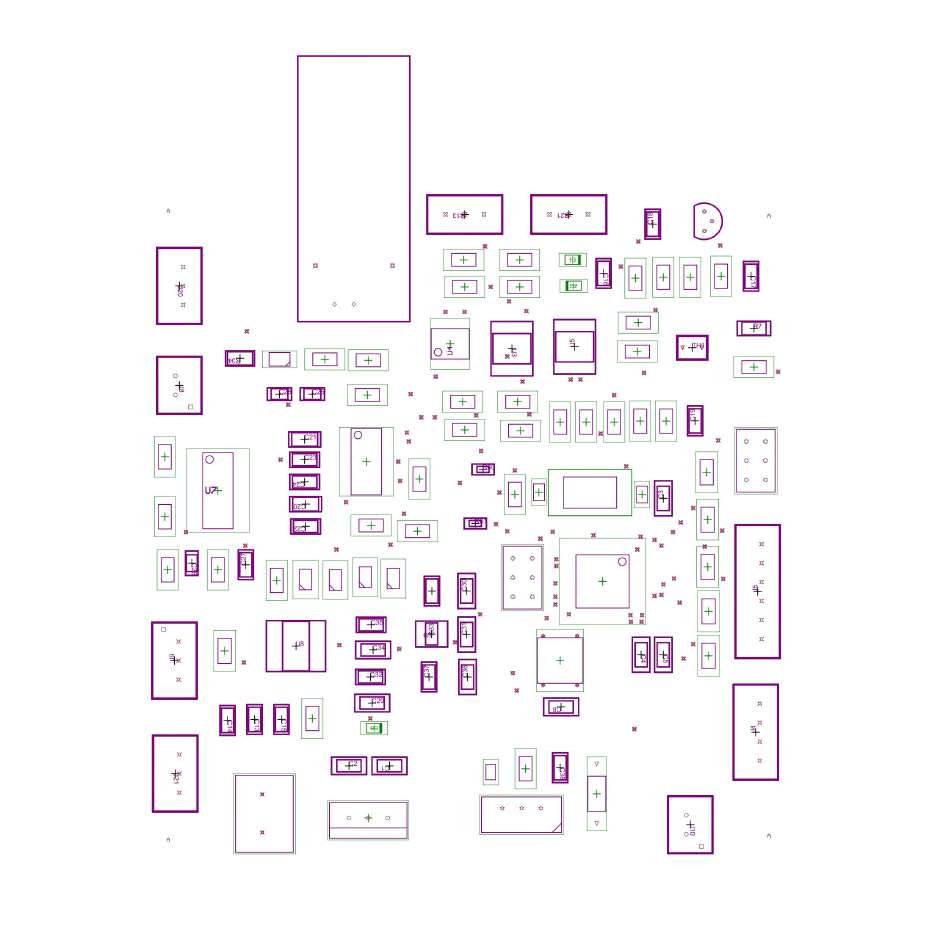
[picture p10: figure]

Figure 25: Drill Drawing for Top-Bottom Layer

14. Drill Guide for Top-Bottom Layer

The drill guide for the top-bottom layer provides detailed instructions and information on the drilling process, ensuring all holes are drilled correctly. It includes drill sizes and the sequence of drilling operations.

Figure 26: Drill Guide for Top-Bottom Layer

### 1.8.3 Gerber Files

Gerber files are essential in the PCB manufacturing process as they provide a standardized format for describing PCB designs to fabrication facilities. They are used to convey detailed information about the PCB layout, including copper traces, drill holes, component placements, solder masks, and more. Each Gerber file corresponds to a specific layer or aspect of the PCB design and is crucial for accurately translating the designer’s intent into physical PCBs. Without Gerber files, manufacturers would lack the precise instructions needed to produce PCBs to the exact specifications required by the designer.

1. Copper Signal Bottom/Top

These Gerber files depict the copper traces and pads on the top and bottom layers of the PCB. They show the conductive pathways that connect components and provide electrical connectivity across the board operations.

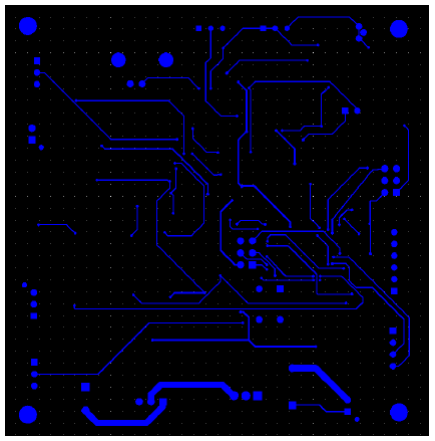
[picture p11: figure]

(a) Copper Signal Top | (b) Copper Signal Bottom

Figure 27: Copper Signal Bottom/Top

2. Legend Bottom/Top

The legend files indicate component outlines, reference designators, and other textual information needed for assembly and identification of components on the PCB. Since all the components are on the top, only legend top file is shown below.

Figure 28: Legend Top

3. NPTH Drill

Non-plated through-hole (NPTH) drill files specify locations and sizes of holes that do not require electrical connection between layers, such as mounting holes or test points. Since there are no non-plated through-holes the file is not shown.

4. Paste Top/Bottom

These files define where solder paste should be applied during the PCB assembly process, aiding in the precise deposition of solder for surface-mount components. Since all the components are on the top, only top file is shown below.

Figure 29: Paste Top

5. Profile

The profile file outlines the outer dimensions and board outline, including cutouts and cut lines, ensuring the PCB is manufactured to the correct shape and size. Here, only the outer margin is cut-off.

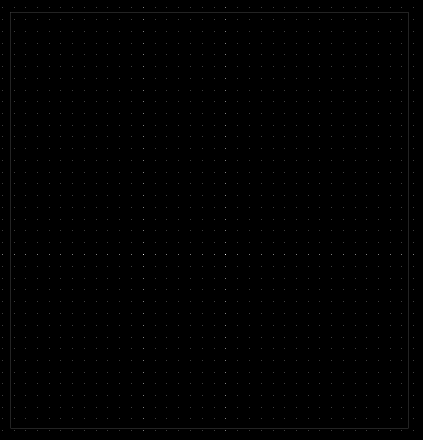
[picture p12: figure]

Figure 30: Profile

6. PTH Drill

Plated through-hole (PTH) drill files specify locations and sizes of holes that require electrical connection between layers, typically for through-hole components.

Figure 31: PTH Drill

7. Soldermask Top/Bottom

These files define areas on the PCB where solder mask should be applied. Solder mask protects copper traces from oxidation and unintended solder bridges during assembly.

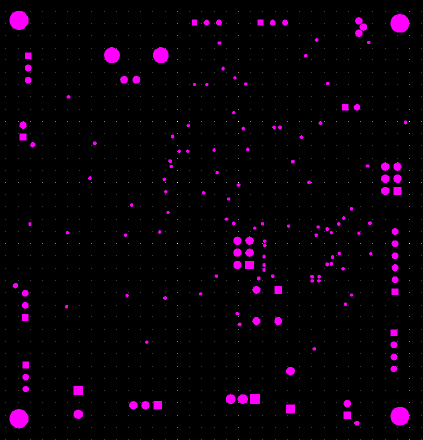
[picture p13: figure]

(a) Soldermask Bottom | (b) Soldermask Top

Figure 32: Soldermask Bottom/Top

### 1.8.4 NC drill File

The NC (Numerically Controlled) drill file is a critical component of PCB manufacturing, detailing the locations and sizes of all drill holes required in the PCB design. Unlike Gerber files which describe the copper traces and layers, the NC drill file specifically focuses on the drilling aspect of the PCB fabrication process. It provides precise coordinates and diameters for both plated through-holes (PTH) and non-plated through-holes (NPTH) based on the design requirements. This file guides the CNC (Computer Numerical Control) drilling machines in creating holes for mounting components, creating vias, and providing electrical connections between different layers of the PCB. Ensuring accuracy in the NC drill file is crucial as it directly impacts the alignment, functionality, and overall quality of the printed circuit board during assembly and operation.

Figure 33: NC Drill Drawing

### 1.8.5 Bill of Materials

Figure 34: Bill of Materials - Page 1

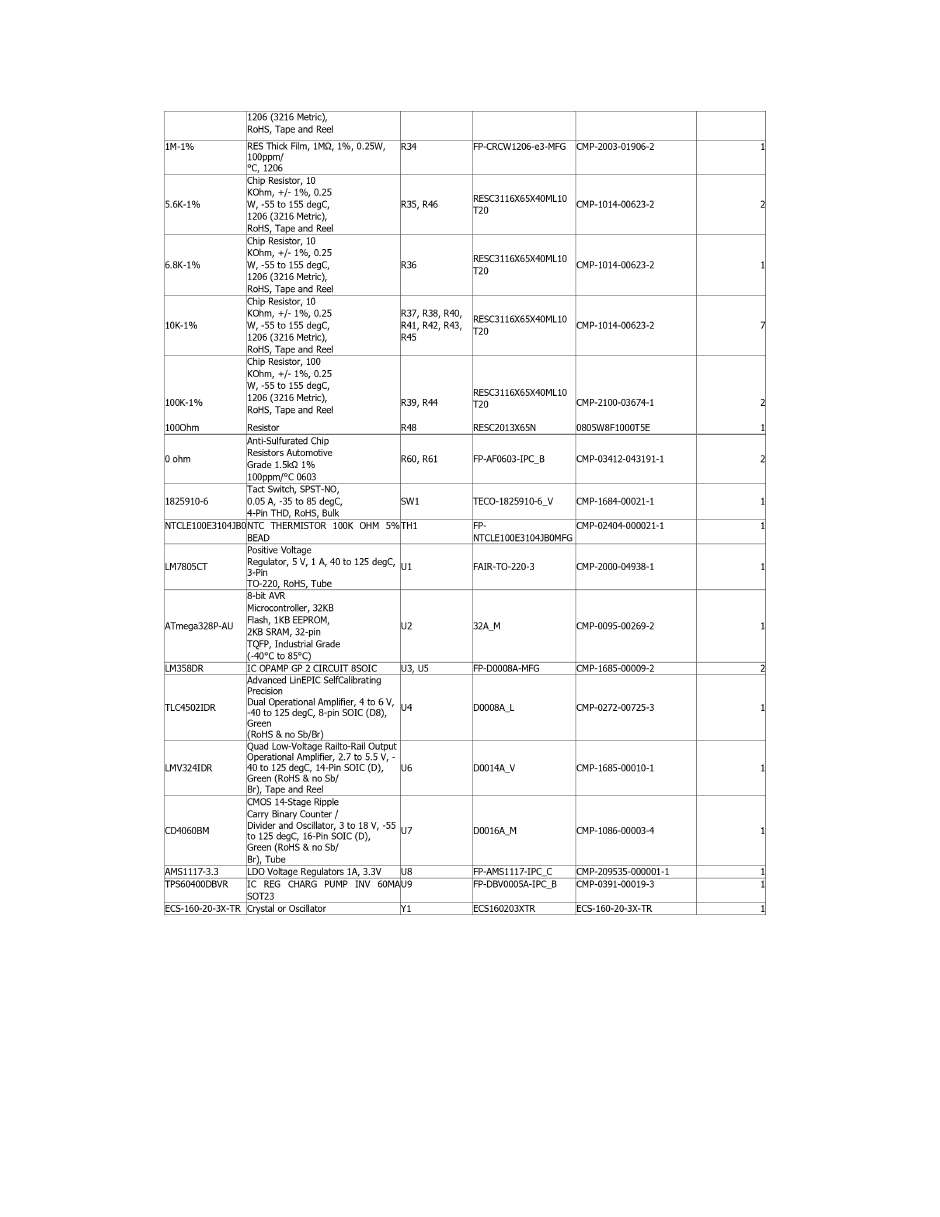
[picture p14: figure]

Figure 35: Bill of Materials - Page 2

### 1.9 Photographs of the PCB

### 1.9.1 Photographs of the Bare PCB

(a) Unsoldered PCB Top
(b) Unsoldered PCB Bottom

Figure 36: User Interface Enclosure - Back

### 1.9.2 Photographs of the Soldered PCB

Figure 37: Soldered PCB

### 1.10 Solidwork Design

### 1.10.1 Sub-assemblies and their specifications

## Components List

1. LCD Display 16X4
- Specifications:

– Voltage Requirements: 5V DC
– Supply current : 1.5mA (at 5V supply voltage)
– Type: Liquid Crystal Display (LCD) with 16 characters per line and 4 lines.
– Resolution: Typically 5x8 dot matrix character resolution per character space.
– Interface: Uses I2C (Inter-Integrated Circuit) or parallel interface for communication. – Backlight: Equipped with a backlight for visibility in various lighting conditions.
– Dimensions: 87.0 x 60.0 mm
2. I2C Module
- Specifications:

– Operating Voltage: 5V DC
– I2C Control: PCF8574
– Maximum Modules: 8 on a single I2C bus
– I2C Address: 0x20 0x27 (default address 0x20, adjustable via onboard jumper pins)
3. Piezo buzzer
- Specifications:

– Buzzer Type: Piezoelectric sound pressure level 95 dB – Operating Voltage: 3-24VDC
– Operating current : 10 mA - 50 mA
– Alarm Diameter: 22mm / 0.86”
– Alarm Height: 10mm / 0.39”
– Mounting Holes Distance: 30mm / 1.18”
4. Wifi Module
- Specifications:

– Model: ESP-01S
– Operating Voltage: 3.3V DC (requires a proper 3.3V voltage regulator if using with 5V systems; IO pins are 5V tolerant)
– WiFi Protocol: 802.11 b/g/n
– Frequency: Operates at 2.4 GHz frequency band
– Power Management: Integrated PLLs, regulators, DCXO, and power management units – Temperature Sensor: Integrated temperature sensor for monitoring onboard temperature – Antenna: Supports antenna diversity for better signal reception
5. DC motor
- Specifications:

– Model: GA25-370
– Rated Power: 3.5W
– Rated Voltage: 12VDC
– Rated Current: 0.06A
– Product Type: Brush DC motor – Rotations Per Minute (RPM): 50

– Outer Diameter: 25 mm (Approx.) – Shaft Diameter: 3 mm (Approx.) – Shaft Length: 10 mm (Approx.) – Weight: 96g (Approx.)

6. On/Off switches
- Specifications:

– Black Mini 3-Pin On/Off Rectangular Rocker Switch SPST – Rating: 6A 250VAC / 10A 125VAC

7. Push buttons
- Specifications:

– Contact Type: Momentary Contact
– Switch Size (Approx.): 16.5x8mm (WxH) – Number of pins: 4
8. 1 PCB

## Selection Criteria for the components

1. LCD Display 16X4
- Display Size and Resolution: Provides clear and readable information to users with a 16x4 character configuration.
- Power Consumption: Efficient use of energy resources to prolong device operation.
2. Piezo Buzzer
- Sound Pressure Level: Produces a sound pressure level of 95 dB for effective audible alerts.
- Voltage Range: Operates efficiently within a 3-24VDC range.
3. WiFi Module
- Model and Protocol: ESP-01S model supporting WiFi 802.11 b/g/n protocol.
- Voltage Compatibility: Operates at 3.3V DC with 5V tolerant IO pins.
4. DC Motor
- Specifications: GA25-370 model with 12VDC, 3.5W power rating.
- Efficiency: Runs at 50 RPM with low current draw (0.06A) for energy efficiency.
- Torque: Stall torque of 10.5 kgf.cm and operating torque of 660 gf.cm suitable for rotating a screw conveyor to dispense fish feed.
- Stall current: Stall current of 2A. The motor’s requirements can be met without overheating or voltage drops.
5. Push Buttons
- Contact Type and Size: Momentary contact, 16.5x8mm (WxH) suitable for user interaction.
- Number of Pins: 4 pins per button, compatible with device control interface.
6. On/Off Switches
- Rating: SPST switches rated for 6A 250VAC / 10A 125VAC.
- Size and Mounting: Compact design suitable for integration into the user interface enclosure.

### 1.10.2 Solidworks Design

The enclosure design for our aquaculture monitoring and feeding system plays a crucial role in ensuring the reliability, durability, and functionality of the device in diverse environmental conditions. This section outlines the detailed design considerations and features for the two main enclosures:

- The Interface Enclosure (Control Unit Housing Enclosure)
- Feeder Enclosure

Each enclosure is meticulously designed to house specific components and functionalities essential to the operation and performance of our innovative aquaculture solution.

## 1) The User Interface Enclosure (Control Unit Housing Enclosure)

- Purpose: The Interface Enclosure serves as the protective housing for the core electronic components and user interface elements of our aquaculture monitoring system. It is designed to withstand environmental challenges while ensuring seamless operation and user interaction.

The user interface provides a clear display where users can monitor pH, temperature, and TDS values of the tank in real-time. Additionally, it allows users to schedule feeding times and provides manual control options to switch the feeder ON or OFF for dispensing feed as needed. This intuitive interface ensures that users can easily manage and optimize their aquaculture environment for fish health and growth.

- Draft Angles: 1 degree applied to all enclosure walls.
- Design Considerations:

– Mounting Options: Provision for secure mounting to ensure stability and accessibility for maintenance tasks. Ability to mount securely onto fish tanks with varying rim thicknesses.

– Aesthetic Appeal: Smooth, uniform surface finish enhances visual appeal.

– Dimensional Requirements: Dimensions are optimized to accommodate all internal components while allowing for efficient wiring and ventilation.

– User-friendly Design: The interface enclosure is designed with intuitive controls and a clear display, ensuring ease of navigation and operation for users.

– Compact Design: The compact enclosure design optimizes space utilization while accommodating all necessary components, minimizing footprint without compromising functionality.

- Rough sketches

- PCB dimension and integration
(a) Dimentions for mounting the PCB in enclosure | (b) PCB mounted in the enclosure

Figure 38: Two Pictures Side by Side

1. Main body:
Model tree of main box

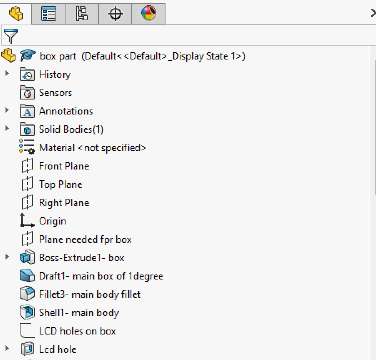
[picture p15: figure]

(a) 1 | (b) 2

Figure 39: model tree

Figure 40: 3

(a) Front face of the main body:

Figure 41: Front Face of the Main Body

- Space for Push Buttons: The front face of the enclosure is designed to include spaces for four push buttons, each with a diameter of 16.5 mm. These buttons serve the following functions:
– OK/Menu: For selecting menu options and confirming actions.
– Cancel: For exiting menus or canceling actions.
– Up/Down: For navigating through menu options and adjusting settings.
– Manual Control: For manually switching the feeder on and off to dispense feed.
- Space for LCD Display: The front face also includes space for a 16x4 LCD display. This display is used to clearly show the sensed levels of pH, temperature, and TDS, as well as any warning messages. The resolution of the display was considered during selection to ensure it provides clear and readable information to the user.
(b) Sides of the Device:
- Buzzer Space: The sides of the device include a designated space for the buzzer and its mounts. A pattern of holes is provided to allow the alarm noise to be heard clearly outside the enclosure, despite the buzzer being located inside.

Figure 42: Buzzer placement inside the enclosure

- Sensor Probes Wires and Power Supply Inlet :

– Sensor Probes Wires and wire connecting to the Feeder: There are specific spaces for the wires of the sensor probes and to the feeder to pass through, ensuring a neat and organized arrangement.
– Power Supply Inlet: The enclosure includes a 12V DC female jack for the power supply inlet, allowing for easy and secure connection to the power source.

Figure 43: Openings for sensor probe wires

Figure 44: 12V DC female ja

- Power ON/ Off switch: Space for a Rotary ON/OFF switch is implemented at the side.

Figure 45: Rotary switch

(c) pH Sensor Consideration: Special consideration has been given to the pH sensor’s female jack, which is mounted on the PCB and protrudes outside the enclosure. Ample space has been created to accommodate this component, ensuring it is securely positioned and easily accessible.

Figure 46: Dimensions for the PH sensors Jack were carefully calculated

(d) Inside the device:

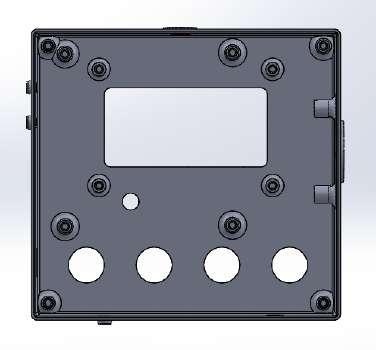
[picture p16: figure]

Figure 47: Interior of the enclosure

- PCB Mounts: Secure mounts with precise dimensions to hold the PCB in place.
- Buzzer and LCD Mounts: Dedicated mounts to firmly position the buzzer and LCD display.
- Lid Mounts: Secure mounts to fix the lid tightly to the enclosure.
- Component Placement: Carefully selected dimensions to prevent interference between components.

(e) Assembly:

Figure 48: Assembled front face of the enclosure

Figure 49: Assembled Interior of Enclosure

(f) Lid:
Model tree of lid
(a) 1 | (b) 2

Figure 50: Lid of the Interface enclosure

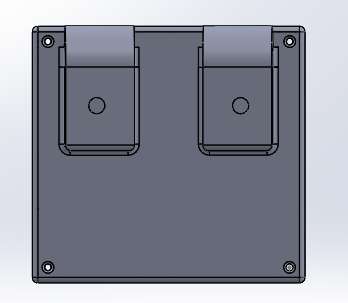
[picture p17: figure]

(a) Inside of Lid | (b) Outside of lid

Figure 51: Lid of the Interface enclosure

(g) Assembly of the device:

Figure 52: Assemble of the Interface enclosure

We will secure the interface enclosure to the rim of the fish tank using hooks on the lid. Adjustable screws will be used to firmly hold the device in place, ensuring stability and easy access for maintenance when needed.

(a) How the device will be fixed to the tank rim.
(b) Adjustable screws on the lid hooks used for fixing the device on tto the rim of the tank

Figure 53: Lid of the Interface enclosure

(h) Moldability:
1 degree applied to all enclosure walls.

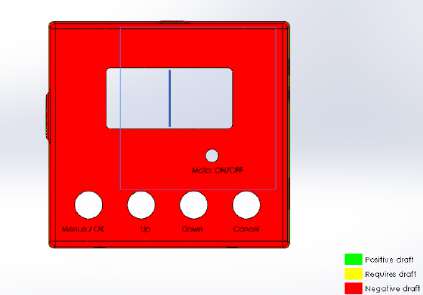
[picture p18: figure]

(a) Draft analysis of main body (1) | (b) Draft analysis of main body (2)

Figure 54: Draft analysis

(a) Draft analysis of lid (1) | (b) Draft analysis of lid (2)

Figure 55: Draft analysis

## 2) Feeder

- Purpose:

– The Feeder Enclosure is designed to house the mechanism responsible for storing and dispensing fish feed at scheduled intervals. It ensures efficient feed management and distribution, crucial for the health and growth of aquatic organisms in our aquaculture system.

q1

- Design Considerations:

– Mounting Options:
∗ Securely mount the DC motor and connected screw conveyor to ensure stable operation, especially during use.
∗ Ensure the feed reservoir is mounted securely, capable of withstanding its weight without compromising device integrity.
∗ Design the feeder to securely mount onto fish tanks with varying rim thicknesses, accommodating different tank configurations for optimal stability and functionality.

– Aesthetic Appeal: Smooth, uniform surface finish enhances visual appeal.

– Dimensional Requirements: Dimensions are optimized to accommodate all internal components while allowing for efficient wiring and ventilation.

– User-friendly Design: The interface enclosure is designed with intuitive controls and a clear display, ensuring ease of navigation and operation for users.

– Compact Design: The compact enclosure design optimizes space utilization while accommodating all necessary components, minimizing footprint without compromising functionality.

- Rough sketches

Figure 56: Sketch of the feeder

Parts of the Feeder:

– Screw Conveyor
– Main Body (housing the screw conveyor and the DC motor)

– Stand

– Feed Reservoir

a) Screw conveyor
How a screw conveyor work: The screw conveyor dispenses food through a rotating helical screw inside a cylindrical housing. When the DC motor is activated, it drives the screw, which moves the feed from the feed reservoir towards the dispensing end. The rotation of the screw ensures a consistent and controlled flow of feed, effectively distributing it to the fish tank.

Figure 57: Mechanism of screw conveyor

The screw conveyor is a critical component responsible for dispensing feed when the DC motor is activated. It rotates via a coupler connected to the DC motor, facilitating efficient feed distribution within the main body. Careful consideration of dimensions ensures optimal performance, allowing for effective dispensation of feed throughout the aquaculture system.

Figure 58: Screw conveyor

Figure 59: Screw conveyor implementation

Model tree of screw conveyor

Figure 60: 1 b) (i)Main body that houses the screw conveyor and the DC motor Model tree of body

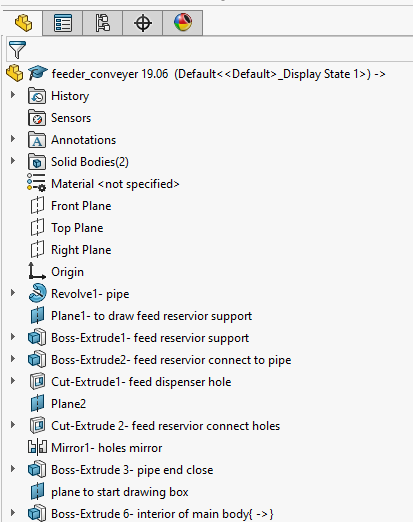
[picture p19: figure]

(a) 1 | (b) 2

Figure 61: modle tree

The main body serves as the central housing unit for the feeder system, accommodating the screw conveyor, DC motor, and feed reservoir. It includes a designated hole for wiring connections from the interface enclosure, facilitating control of the DC motor. This component integrates all essential parts of the feeder system, ensuring efficient operation and coordination between components for precise feed dispensation in aquaculture settings.

(a) Main body (1) | (b) Main body (2)

Figure 62: Main body of the feeder

b) (ii) Lid of the main body Model tree of lid

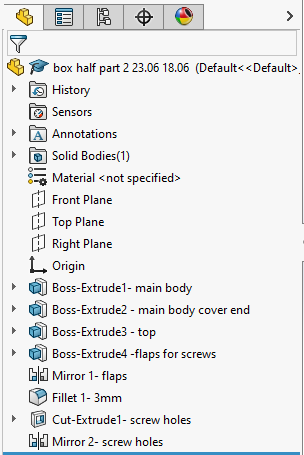
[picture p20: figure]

Figure 63: Model tree

(a) Lid of the main body of the feeder (1) | (b) Lid connected to the main body of the feeder

Figure 64: Main body of the feeder

c) Feed reservoir
Model tree of food reservoir and its lid

The feed reservoir serves as a container to store an adequate amount of feed ready for dispensing. It is designed with sufficient capacity to meet the feeding needs of the aquaculture system. The reservoir is securely held by the device, ensuring stability and preventing any weight-related issues. Additionally, it features a lid to protect the feed from exposure to the environment, maintaining its freshness and quality until dispensation.

(a) Feed reservoir and lid | (b) Feed reservoir assembled on the feeder

Figure 66: Main body of the feeder

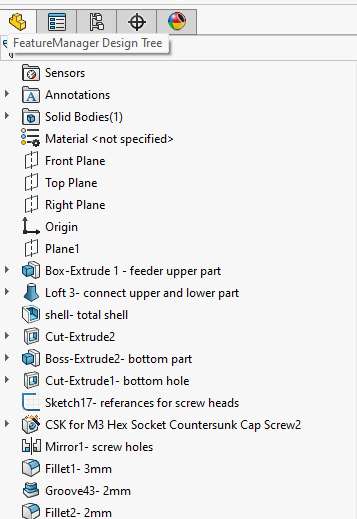
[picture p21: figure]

(a) Model tree of feed reservoir | (b) Model tree of lid

Figure 65: Model tree

d) Stand
Model tree of stand

The stand is constructed from iron for robustness and durability, providing sturdy support to securely hold the feeder device in place. Its primary function is to fix the device to the rim of the fish tank using four adjustable screws, ensuring stability and preventing movement during operation. The stand is designed with sufficient thickness to bear the weight of the device effectively. It is connected to the feeder device in a manner that distributes the weight evenly, minimizing the risk of tipping or instability. This ensures the feeder remains securely positioned for reliable operation in aquaculture environments.

Figure 67: Model tree of feeder stand

(a) The iorn stand (1) | (b) The iorn stand (2)

Figure 68: The stand that holds the device and fix it to the rim of the tank

How the stand holds the device in place:

(a) The iorn stand (1)

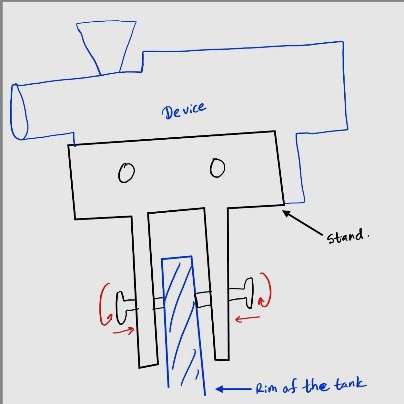
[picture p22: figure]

(b) sketch of hoe the device is fixed to the rim of the tank

Figure 69: The stand that holds the device and fix it to the rim of the tank

- Final Assembly:

Figure 70: Final feeder Assembly

(a) Assembly of the feeder | (b) Feeder assembly

Figure 71: Feeder assembly

### 1.10.3 Standardization and Industrial Design

- Adherence to Standards: By adhering to industry standards and principles of industrial design, the monitoring / management system and feeder exhibits standardized features and ergonomic considerations, ensuring compatibility with user expectations and industry norms.
- User-Friendly Design: The device incorporates a user-friendly design with standardized components and thoughtful placement, enhancing usability and accessibility. This alignment with industrial design standards promotes ease of maintenance, operation, and overall user satisfaction.

Standards used:

- Electrical Safety Standards:

– Compliance with IEC 60950-1 or equivalent for electrical safety of information technology equipment.

– Ensure components and wiring meet applicable safety standards for electrical appliances.

- Environmental Protection (Waterproofing):

– Adherence to mechanical design standards (e.g., ASME Y14.5) ensures proper fit, tolerance, and structural integrity of components. This enhances durability and operational efficiency under varying environmental conditions typical in aquaculture settings.

- Component and Connector Standards:

– Using connectors compliant with IEC 60603 or equivalent for connectors used in electronic equipment.

– Ensuring connectors and components meet relevant environmental and electrical standards for reliability and durability.

- Assembly and Mounting Considerations:

– Providing secure mounting options with adjustable screws and hooks suitable for various tank rim thicknesses.

– Ensuring ease of assembly and maintenance with clear access points for wiring and component servicing.

- Ergonomic and User Interface Standards:

– Following ergonomic design principles (e.g., ISO 9241) ensures user-friendly interfaces and intuitive controls. Our system integrates clear displays and ergonomic button placements to facilitate ease of use and efficient monitoring of aquaculture parameters.

- Industrial Design Principles:

– Integrating industrial design principles for standardized features and aesthetic appeal.

– Ensuring the system meets expectations for usability, maintenance, and operational efficiency.

### 1.11 Drawings

### 1.11.1 User Interface enclosure

## a)Main box (dimensions in millimeters)

Figure 72: Main box

## a)Lid of the user interface enclosure (dimensions in millimeters)

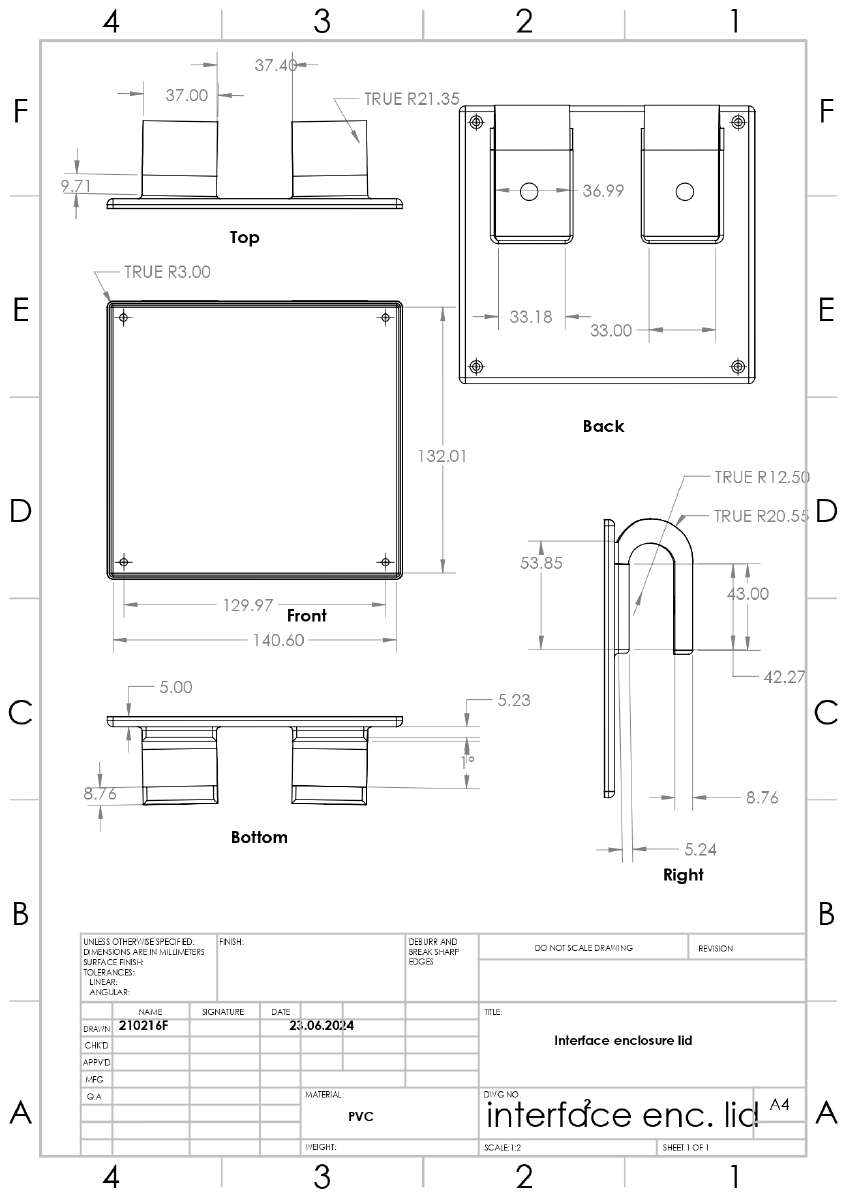
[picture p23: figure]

Figure 73: Lid

### 1.11.2 Feeder enclosure

## a)Feeder main body (dimensions in millimeters)

Figure 74: Feeder main body

## b) Lid of Feeder main body (dimensions in millimeters)

Figure 75: Feeder main body lid

## c) Screw conveyor (dimensions in millimeters)

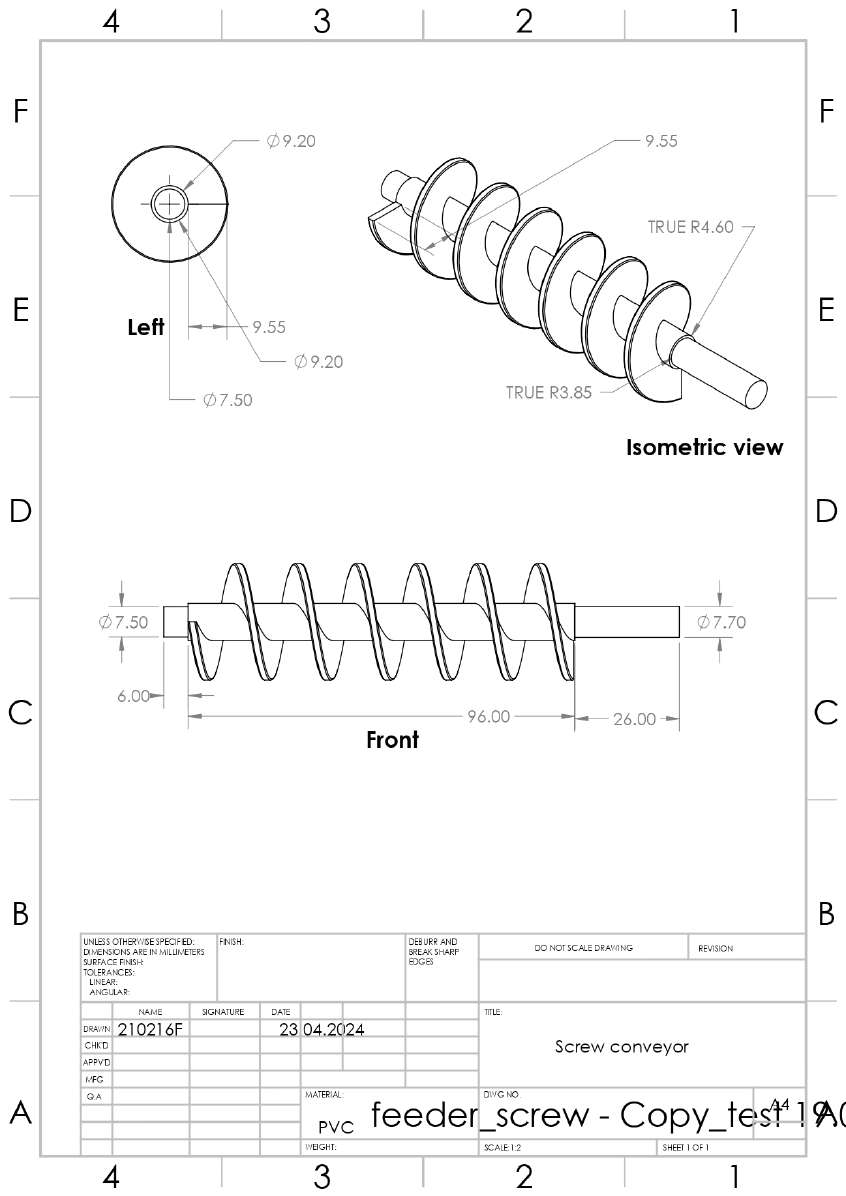
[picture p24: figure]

Figure 76: Screw conveyor

## d) Feed reservoir (dimensions in millimeters)

Figure 77: Feed reservoir

## e) Feed reservoir lid (dimensions in millimeters)

Figure 78: Feed reservoir lid

## f) Stand (dimensions in millimeters)

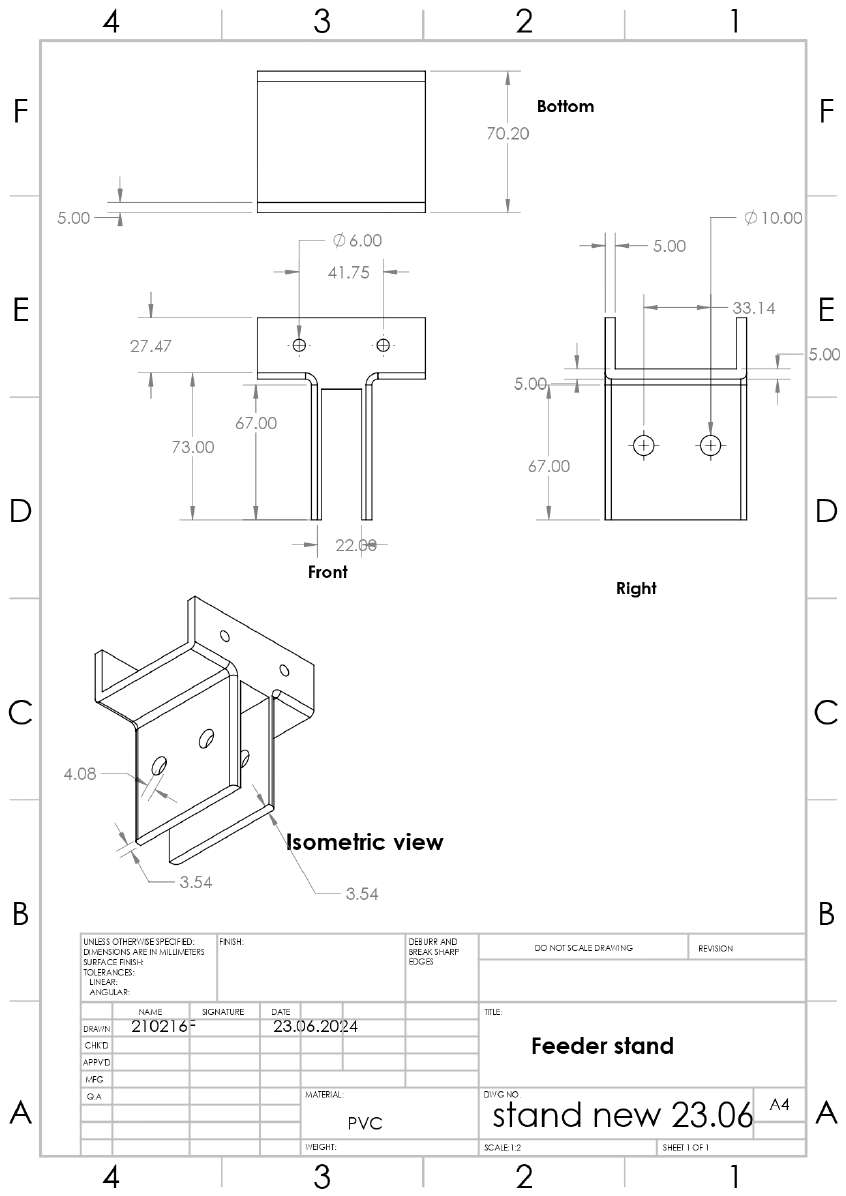
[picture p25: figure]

Figure 79: Feeder stand

### 1.12 Photographs of physically built enclosures

### 1.12.1 User Interface enclosure

(a) Interface Enclosure - image 1 | (b) Interface Enclosure - image 2

Figure 80: User Interface Enclosure - Back

(a) Interface Enclosure Lid - image 1 | (b) Interface Enclosure Lid - image 2

Figure 81: User Interface Enclosure - Lid

## Main body of the feeder

### 1.12.2 Feeder

(a) Main Body of the Feeder - image 1 | (b) Main Body of the Feeder - image 2

Figure 82: Main Body of the Feeder

## Back Lid of the Feeder Main Body

(a) Back Lid - image 1 | (b) Back Lid - image 2

Figure 83: Back Lid of the Feeder Main Body

## Screw Conveyor Spiral

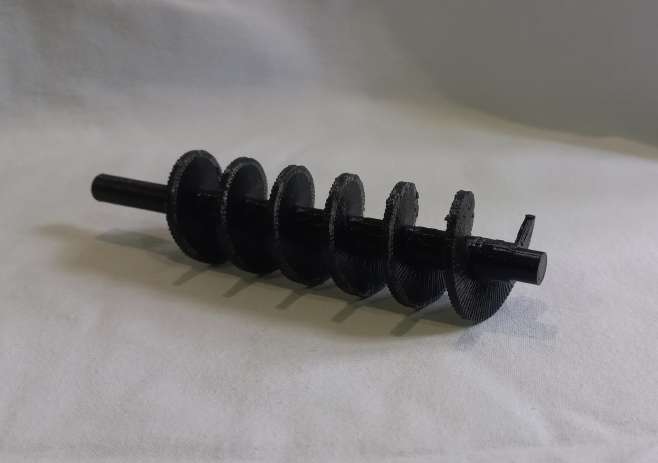
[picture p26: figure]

Figure 84: Screw conveyor Spiral

## Food Container

(a) Food Container - image 1 | (b) Food Container - image 1

Figure 85: Stand

## Stand

(a) Feeder Stand - image 1 | (b) Feeder Stand - image 2

Figure 86: Feeder Stand

### 1.13 Firmware Development/Algorithm Implementation

AVR Code:

In our project, we opted for register-level programming and direct port manipulation instead of relying on standard Arduino libraries. This approach enabled us to optimize the code for speed and efficiency.
To achieve precise control over delays, we developed custom delay functions using timer registers. By configuring the timer to generate interrupts at specific intervals, we created accurate microsecond and millisecond delays. This method ensured the precision necessary for our application.
For efficient communication between the microcontroller and other devices, we developed a custom UART library. This approach allowed us to tailor the code to the specific requirements of our application, ensuring reliable and fast data transmission crucial for real-time operations.
Additionally, we required several other libraries, including DS18B20.h, SoftwareSerial.h, LiquidCrystal I2C.h, and WifiEspAT.h. These libraries, originally developed as Arduino libraries by various contributors, were converted into C++ libraries with register-level coding. We modified the functions within these libraries to meet the specific needs of our project, ensuring seamless integration and optimal performance.

### 1.13.1 Main code

1 | # include < avr / io .h >
2 | # include < stdint .h >
3 | # include < stdbool .h >
4 | # include < stdio .h >

5
6 | # include " DS18B20 .h"
7 | # include " SoftwareSerial .h"
8 | # include " WifiEspAT .h"
9 | # include " LiquidCrystal_I2C .h"
10 | # include " uart .h"
11 | # include " delay .h"

12
13 | // Define macros for register - level access for OneWire
14 | # define PIN_TO_BITMASK ( pin ) (1 << ( pin ) )
15 | # define DIRECT_MODE_INPUT ( base , mask ) (*( base - 1) ) &= ~( mask )

16
17 | // Define LCD pins
18 | # define LCD_SDA PC4
19 | # define LCD_SCL PC5

20
21 | // Pushbuttons
22 | # define PB_cancel PD2
23 | # define PB_OK PD3
24 | # define PB_UP PD4
25 | # define PB_DOWN PD5

26
27 # define MOTOR_BUTTON PD6

28
29 | // Buzzer pin
30 | # define BUZZER PB3

31
32 | // Feeder Motor pin
33 | # define MOTOR_PIN PD7

34
35 | // TDS pin
36 | # define TdsSensorPin PC2

37
38 | // PH pin
39 | # define PhSensorPin PC3

40
41 | // Temp pin
42 | # define ONE_WIRE_BUS PB0

43
44 | // WiFi pins
45 | # define ESP_TX PD0
46 | # define ESP_RX PD1

47

48 | // Ranges
49 | int h_temp = 25;
50 | int l_temp = 2;

51
52 | float phMinValue = 6.5;
53 | float phMaxValue = 8.0;

54
55 | float tdsMinValue = 300;
56 | float tdsMaxValue = 1000;

57
58 | // WiFi and NTP settings
59 | const char * ssid = " MyHomeNetwork ";
60 | const char * passphrase = " 123 home ";
61 | const char * ntpServerName = " pool . ntp .org ";
62 | # define NTP_PORT 123

63

64

65
66 | // Motor control variables
67 | int motor_hour = 0; | // Hour for motor activation
68 | int motor_minute = 0; | // Minute for motor activation
69 | bool motor_triggered = false ; | // Flag to track motor activation
70 | int motor_duration = 10; | // Default motor rotation duration in seconds

71
72 | // Menu
73 | int current_mode = 0 , max_modes = 4; | // Increased max_modes for additional sensor
74 | String modes [] = { "1- Temp range ", "2- pH range ", "3- TDS range ", "4- Set Alarm 2", "5-
Set Motor Time ", "6- Set Motor Duration " };

75
76 // For temperature sensor

77
78 | // For pH sensor
79 | float phCalibrationValue = 21.34;
80 | int phBufferArr [10] , phTemp ;

81
82 | // For TDS sensor
83 | # define VREF 5.0
84 | # define SCOUNT 30
85 | int tdsAnalogBuffer [ SCOUNT ];
86 | int tdsAnalogBufferTemp [ SCOUNT ];
87 | int tdsAnalogBufferIndex = 0;
88 | int tdsCopyIndex = 0;
89 | float tdsAverageVoltage = 0;
90 | float tdsValue = 0;
91 | float temperature = 16; | // Initial temperature for compensation

92

93
94 | // for alarm
95 | bool should_ring_alarm = false ; | // Flag to control alarm ringing

96
97 | // Notes for the buzzer melody
98 | int notes [] = { 262 , 294 , 330 , 349 , 392 , 440 , 494 };

99
100 | // Number of notes in the melody
101 | int n_notes = 7;

102

103

104
105 | // Function Prototypes
106 | void WiFi_init ( const char * ssid , const char * passphrase );
107 | void NTPClient_sendRequest () ;
108 | bool NTPClient_receiveResponse ( uint32_t * time ) ;
109 | void get_current_time ( uint32_t epochTime , int * hours , int * minutes , int * seconds );
110 | void OneWire_begin ( uint8_t pin );
111 | void connectToWiFi () ;
112 | void setup () ;
113 | void loop () ;
114 | int main () ;
115 | void update_time_with_check_motor () ;
116 | int wait_for_button_press () ;
117 | void go_to_menu () ;
118 | void set_motor_activation_time () ;
119 | void set_motor_duration () ;

120 | void display_motor_status () ;
121 | void set_temp_range () ;
122 | void set_ph_range () ;
123 | void set_tds_range () ;
124 | void run_mode ( int mode ) ;
125 | void adc_init () ;
126 | uint16_t adc_read ( uint8_t channel ) ;
127 | void check_sensors () ;
128 | void ring_alarm () ;

129
130 | // Initialize UART communication and send AT commands to connect to WiFi
131 | void WiFi_initAndConnect ( const char * ssid , const char * passphrase ) {
132 | // Initialize UART communication
133 | UART_INIT () ;

134
135 | // Send AT commands to connect to WiFi
136 | UART_SEND ("AT+ CWJAP =\" ") ;
137 | UART_SEND ( ssid );
138 | UART_SEND ("\" ,\"");
139 | UART_SEND ( passphrase );
140 | UART_SEND ("\"\ r\n") ;
141 | }

142
143 | // Send NTP request packet using UART commands to establish a UDP connection and send
| NTP request packet
144 | void NTPClient_sendRequest () {

145
146 | UART_SEND ("AT+ CIPSTART =\" UDP \" ,\"");
147 | UART_SEND ( NTP_SERVER );
148 | UART_SEND ("\" ,");
149 | UART_SEND ( NTP_PORT ) ;
150 | UART_SEND ("\r\n");

151
152 | // Construct and send NTP request packet
153 | uint8_t packetBuffer [48] = {0};
154 | packetBuffer [0] = 0 b11100011 ; | // NTP request header
155 | packetBuffer [1] = 0; | // Mode
156 | packetBuffer [2] = 6; | // Stratum
157 | packetBuffer [3] = 0 xEC ; | // Poll Interval
158 | packetBuffer [12] = 49; | // NTP Magic String
159 | packetBuffer [13] = 0 x4E ;
160 | packetBuffer [14] = 49;
161 | packetBuffer [15] = 52;

162
163 | UART_SEND ( packetBuffer , sizeof ( packetBuffer )) ; // Send the packet
164 | }

165
166 | // Receive and parse the NTP response via UART
167 | bool NTPClient_receiveResponse ( uint32_t * time ) {
168 | // Receive NTP response via UART
169 | uint8_t packetBuffer [48] = {0};
170 | int index = 0;

171
172 | while ( index < sizeof ( packetBuffer )) {
173 | uint8_t byte = UART_RECEIVE () ;
174 | packetBuffer [ index ++] = byte ;
175 | }

176
177 | // Parse the response
178 | uint32_t highWord = ( packetBuffer [40] << 8) | packetBuffer [41];
179 | uint32_t lowWord = ( packetBuffer [42] << 8) | packetBuffer [43];
180 | uint32_t secsSince1900 = ( highWord << 16) | lowWord ;
181 | * time = secsSince1900 - 2208988800 UL ;
182 | return true ;
183 | }
184 | // Convert epoch time to hours , minutes , and seconds
185 | void get_current_time ( uint32_t epochTime , int * hours , int * minutes , int * seconds ) {
186 | // Convert epoch time to struct tm
187 | time_t rawTime = ( time_t ) epochTime ;
188 | struct tm * timeInfo = gmtime (& rawTime ); // gmtime converts epoch time to GMT

189
190 | if ( timeInfo != NULL ) {
191 | * hours = timeInfo -> tm_hour ;

192 | * minutes = timeInfo -> tm_min ;
193 | * seconds = timeInfo -> tm_sec ;
194 | } else {
195 | * hours = * minutes = * seconds = -1; // Error value
196 | }
197 | }

198
199 | // Set the specified pin as an input for the OneWire communication
200 | void OneWire_begin ( uint8_t pin ) {
201 | // Set pin direction to INPUT
202 | DIRECT_MODE_INPUT (& DDRB , PIN_TO_BITMASK ( pin ) );
203 | }

204
205 | void setup () {
206 | // initiate serial communication with wifi
207 | SoftwareSerial_Init (Rx - pin , Tx_pin ,9600) ;
208 | // start communication with tempreature pin
209 | OneWire_begin ( TempSensorPin );

210
211 | // Initialize UART ( Serial ) at 9600 baud
212 | UBRR0H = 0; // Set baud rate to 9600
213 | UBRR0L = 16; // Set baud rate to 9600
214 | UCSR0B |= (1 << RXEN0 ) | (1 << TXEN0 ); // Enable RX and TX
215 | UCSR0C |= (1 << UCSZ01 ) | (1 << UCSZ00 ); // Set data bits to 8

216
217 | // Set input pins
218 | DDRD &= (~(1 < < DDD2 )); // Set PD2 ( PD2 ) as input
219 | DDRD &= (~(1 < < DDD3 )); // Set PD3 ( PD3 ) as input
220 | DDRD &= (~(1 < < DDD4 )); // Set PD3 ( PD4 ) as input
221 | DDRD &= (~(1 < < DDD5 )); // Set PD5 ( PD5 ) as input
222 | DDRD &= (~(1 < < DDD6 )); // Set PD5 ( PD5 ) as input

223
224 | DDRC &= (~(1 < < DDC2 )); // Set TDS_PIN ( PC2 ) as input
225 | DDRC &= (~(1 < < DDC3 )); // Set PH_PIN (PC3) as input

226
227 | DDRB &= (~(1 < < DDB0 )); // Set TempSensorPin ( PB0 ) as input

228
229 | DDRD &= (~(1 < < DDD0 )); // Set ESP_RX (PD0) as input
230 | DDRD &= (~(1 < < DDD1 )); // Set ESP_TX (PD1) as input

231
232 | // Set output pins
233 | DDRB |= (1 < < DDB3 ); // Set BUZZER ( PB3 ) as output
234 | DDRD |= (1 < < DDD7 ); // Set MOTOR_PIN (PD7) as output

235
236 | // Connect to WiFi
237 | connectToWiFi () ;

238
239 | // Initialize time client
240 | NTPClient_init ( ssid , passphrase ) ;

241
242 | // Initiate tempreature sensor
243 | DS18B20_Init ( TempSensorPin );

244
245 | // Initialize LCD
246 | // Adjust the address and dimensions according to your LCD module
247 | lcd_init (0 x27 , 16 , 2) ;
248 | lcd_backlight () ; | // Turn on the backlight
249 | lcd_clear () ;
250 | lcd_setCursor (0 , 0) ;
251 | lcd_write (" welcome !");
252 | delay_ms (2000) ;
253 | lcd_clear () ;
254 | }

255
256 | void loop () {
257 | update_time_with_check_motor () ;
258 | check_sensors () ;
259 | if (!( PIND & (1 << PB5 ) )) {
260 | delay_ms (200) ;
261 | go_to_menu () ;
262 | }
263 | }

264

265 | int main () {
266 | setup () ;
267 | while (1)
268 | {
269 | loop () ;
270 | }
271 | }

272

273
274 | void connectToWiFi () {
275 | // Initialize the WiFi library
276 | WiFi_init () ;
277 | // Connect to WiFi
278 | wifi_begin ( ssid , password );
279 | while ( wifi_status () != WL_CONNECTED ) {
280 | delay_ms (500) ;
281 | }
282 | }

283

284
285 | // Function to update time and check for motor activation
286 | void update_time_with_check_motor () {

287
288 | NTPClient_sendRequest () ;
289 | if ( NTPClient_receiveResponse () ) {
290 | int hours , minutes , seconds ;
291 | get_current_time ( ntpTime , & hours , & minutes , & seconds );

292
293 | // Print time on LCD
294 | lcd_clear () ;
295 | lcd_setCursor (0 , 0) ;
296 | lcd_write ( hours );
297 | lcd_write (":") ;
298 | lcd_write ( minutes );

299
300 | // Check if the manual control is pressed for the motor
301 | int pressed = wait_for_button_press () ;
302 | if ( pressed = MOTOR_PIN ){
303 | // If the Motor is working when MOTOR_BUTTON is pressed , turn it off
304 | if ( PIND & (1 << PD7 )) {
305 | // Stop the motor
306 | PORTD &= ~(1 << PD7 ) ;;
307 | motor_triggered = false ;
308 | lcd_clear () ;
309 | lcd_setCursor (6 , 0) ;
310 | lcd_write (" Motor Off ");

311
312 | // If the Motor is off when MOTOR_BUTTON is pressed , turn it on
313 | } else if (!( PIND & (1 << PD7 )) ) {
314 | // Start the motor
315 | PORTD |= (1 << PD7 );
316 | motor_triggered = true ;
317 | lcd_clear () ;
318 | lcd_setCursor (6 , 0) ;
319 | lcd_write (" Motor On");

320
321 | }
322 | }

323

324
325 | // Check if it ’s time to activate the motor
326 | if (! motor_triggered && hours == motor_hour && minutes == motor_minute ) {
327 | // Start the motor
328 | PORTD |= (1 << PD7 );
329 | motor_triggered = true ;
330 | lcd_clear () ;
331 | lcd_setCursor (0. , 0.) ;

332
333 | lcd_setCursor (6 , 0) ;
334 | lcd_write (" Motor On");

335
336 | delay_ms ( motor_duration * 1000) ; | // Run motor for motor_duration seconds
337 | PORTD &= ~(1 << PD7 ) ;; | // Stop the motor

338 | motor_triggered = false ;
339 | lcd_clear () ;
340 | lcd_setCursor (6 , 0) ;
341 | lcd_write (" Motor Off ") ;
342 | }

343
344 | // Check if motor should be stopped
345 | if ( motor_triggered && ( hours != motor_hour || minutes != motor_minute )) {
346 | // Stop the motor
347 | PORTD &= ~(1 << PD7 ) ;;
348 | motor_triggered = false ;
349 | lcd_clear () ;
350 | lcd_setCursor (0. , 0.) ;
351 | lcd_setCursor (6 , 0) ;
352 | lcd_write (" Motor Off ") ;
353 | }
354 | }
355 | // Continuously check for button presses
356 | int wait_for_button_press () {
357 | while ( true ) {
358 | if (!( PIND & (1 < < PD2 ) )) {
359 | return PB_cancel ;
360 | } else if (!( PIND & (1 < < PD3 )) ) {
361 | return PB_OK ;
362 | } else if (!( PIND & (1 < < PD4 )) ) {
363 | return PB_UP ;
364 | } else if (!( PIND & (1 < < PD5 )) ) {
365 | return PB_DOWN ;
366 | } else if (!( PIND & (1 << PD6 ))) {
367 | return MOTOR_BUTTON ;
368 | }
369 | }
370 | }
371 | /**
372 | * Function to manage the menu interface on an LCD screen .
373 | * This function allows the user to navigate through different modes and select a
| desired mode .
374 | * It handles button presses for navigation (UP , DOWN ) and actions (OK , CANCEL ) while
| updating the display accordingly .
375 | */
376 | void go_to_menu () {
377 | while ( PIND & (1 << PD2 )) {
378 | lcd_clear () ;
379 | lcd_setCursor (0 ,0) ;
380 | lcd_write ( modes [ current_mode ]) ;

381
382 | int pressed = wait_for_button_press () ;
383 | delay_ms (1000) ;

384
385 | if ( pressed == PB_UP ) {
386 | delay_ms (200) ;
387 | current_mode -= 1;
388 | if ( current_mode < 0) {
389 | current_mode = max_modes - 1;
390 | }
391 | } else if ( pressed == PB_DOWN ) {
392 | delay_ms (200) ;
393 | current_mode += 1;
394 | current_mode = current_mode % max_modes ;
395 | } else if ( pressed == PB_OK ) {
396 | delay_ms (200) ;
397 | run_mode ( current_mode );
398 | } else if ( pressed == PB_cancel ) {
399 | delay_ms (200) ;
400 | break ;
401 | }
402 | }
403 | lcd_clear () ;
404 | }

405
406 | // Function to set motor activation time
407 | void set_motor_activation_time () {
408 | int entered_hour = 0;

409 | int entered_minute = 0;

410
411 | // Loop to handle user input for setting motor time
412 | while ( true ) {
413 | lcd_clear () ;
414 | lcd_setCursor (0 , 0) ;

415
416 | // Display prompt and current entered time
417 | lcd_setCursor (6 , 0) ;
418 | lcd_write ("Set Motor Time :");
419 | lcd_setCursor (0 , 1) ;
420 | lcd_write ( String ( entered_hour , DEC ) + ":" + String ( entered_minute , DEC ) );

421
422 | int pressed = wait_for_button_press () ;

423
424 | // Handle button presses to adjust minutes and set the time
425 | if ( pressed == PB_UP ) {
426 | delay_ms (200) ;
427 | entered_minute = ( entered_minute + 1) % 60;
428 | } else if ( pressed == PB_DOWN ) {
429 | delay_ms (200) ;
430 | entered_minute = ( entered_minute - 1 + 60) % 60;
431 | } else if ( pressed == PB_OK ) {
432 | delay_ms (200) ;
433 | motor_hour = entered_hour ;
434 | motor_minute = entered_minute ;

435
436 | // Display confirmation message
437 | lcd_clear () ;
438 | lcd_setCursor (0 , 0) ;
439 | lcd_setCursor (6 , 0) ;
440 | lcd_write (" Motor Time Set");
441 | lcd_setCursor (0 , 1) ;
442 | lcd_write ( String ( motor_hour , DEC ) + ":" + String ( motor_minute , DEC ) );
443 | delay_ms (2000) ;
444 | break ;
445 | } else if ( pressed == PB_cancel ) {
446 | delay_ms (200) ;
447 | break ;
448 | }
449 | delay_ms (100) ;
450 | }
451 | }

452

453
454 | // Function to set motor duration
455 | void set_motor_duration () {
456 | int entered_duration = motor_duration ;

457
458 | while ( true ) {
459 | lcd_clear () ;
460 | lcd_setCursor (0. , 0.) ;
461 | lcd_setCursor (6 , 0) ;
462 | lcd_write ("Set Motor Duration :");
463 | lcd_setCursor (0 , 1) ;
464 | lcd_write ( String ( entered_duration , DEC ) + " sec ");

465

466
467 | int pressed = wait_for_button_press () ;
468 | if ( pressed == PB_UP ) {
469 | delay_ms (200) ;
470 | entered_duration += 1;
471 | } else if ( pressed == PB_DOWN ) {
472 | delay_ms (200) ;
473 | entered_duration = max ( entered_duration - 1 , 1) ; | // Ensure duration is at least 1
| second
474 | } else if ( pressed == PB_OK ) {
475 | delay_ms (200) ;
476 | motor_duration = entered_duration ;
477 | lcd_clear () ;
478 | lcd_setCursor (0. , 0.) ;

479
480 | lcd_setCursor (6 , 0) ;

481 | lcd_write (" Motor Duration Set ") ;
482 | lcd_setCursor (0 , 1) ;
483 | lcd_write ( String ( motor_duration , DEC ) + " sec");

484
485 | delay_ms (2000) ;
486 | break ;
487 | } else if ( pressed == PB_cancel ) {
488 | delay_ms (200) ;
489 | break ;
490 | }
491 | delay_ms (100) ;
492 | }
493 | }

494
495 | // Function to display motor status
496 | void display_motor_status () {
497 | lcd_clear () ;
498 | lcd_setCursor (0. , 0.) ;
499 | lcd_write (" Motor ");
500 | lcd_setCursor (6 , 0) ;
501 | lcd_write ( motor_triggered ? "On" : " Off ") ;
502 | delay_ms (2000) ;
503 | }
504 | // set desired range for tempreature
505 | void set_temp_range () {
506 | int entered_h_temp = 27;
507 | while ( true ) {
508 | lcd_clear () ;
509 | lcd_setCursor (0 ,0) ;
510 | lcd_write (" high temp : " + String ( entered_h_temp ));

511
512 | int pressed = wait_for_button_press () ;

513
514 | if ( pressed == PB_UP ) {
515 | delay_ms (200) ;
516 | entered_h_temp += 1;
517 | entered_h_temp = entered_h_temp % 31;
518 | } else if ( pressed == PB_DOWN ) {
519 | delay_ms (200) ;
520 | entered_h_temp -= 1;
521 | if ( entered_h_temp < 25) {
522 | entered_h_temp = 30;
523 | }
524 | } else if ( pressed == PB_OK ) {
525 | delay_ms (200) ;
526 | h_temp = entered_h_temp ;
527 | break ;
528 | } else if ( pressed == PB_cancel ) {
529 | delay_ms (200) ;
530 | break ;
531 | }
532 | }

533
534 | int entered_l_temp = 27;
535 | while ( true ) {
536 | lcd_clear () ;
537 | lcd_setCursor (0 ,0) ;
538 | lcd_write (" lowest temp : " + String ( entered_l_temp )) ;

539
540 | int pressed = wait_for_button_press () ;

541
542 | if ( pressed == PB_UP ) {
543 | delay_ms (200) ;
544 | entered_l_temp += 1;
545 | entered_l_temp = entered_l_temp % 31;
546 | } else if ( pressed == PB_DOWN ) {
547 | delay_ms (200) ;
548 | entered_l_temp -= 1;
549 | if ( entered_l_temp < 25) {
550 | entered_l_temp = 30;
551 | }
552 | } else if ( pressed == PB_OK ) {
553 | delay_ms (200) ;

554 | l_temp = entered_l_temp ;
555 | break ;
556 | } else if ( pressed == PB_cancel ) {
557 | delay_ms (200) ;
558 | break ;
559 | }
560 | }
561 | }
562 | // set desired range for pH values
563 | void set_ph_range () {
564 | float entered_ph_min = 6.5;
565 | while ( true ) {
566 | lcd_clear () ;
567 | lcd_setCursor (0 ,0) ;
568 | lcd_write ("pH Min: " + String ( entered_ph_min )) ;

569
570 | int pressed = wait_for_button_press () ;

571
572 | if ( pressed == PB_UP ) {
573 | delay_ms (200) ;
574 | entered_ph_min += 0.1;
575 | if ( entered_ph_min > 14.0) {
576 | entered_ph_min = 6.5;
577 | }
578 | } else if ( pressed == PB_DOWN ) {
579 | delay_ms (200) ;
580 | entered_ph_min -= 0.1;
581 | if ( entered_ph_min < 0.0) {
582 | entered_ph_min = 0.0;
583 | }
584 | } else if ( pressed == PB_OK ) {
585 | delay_ms (200) ;
586 | phMinValue = entered_ph_min ;
587 | break ;
588 | } else if ( pressed == PB_cancel ) {
589 | delay_ms (200) ;
590 | break ;
591 | }
592 | }

593
594 | float entered_ph_max = 8.0;
595 | while ( true ) {
596 | lcd_clear () ;
597 | lcd_setCursor (0 ,0) ;
598 | lcd_write ("pH Max: " + String ( entered_ph_max )) ;

599

600
601 | int pressed = wait_for_button_press () ;

602
603 | if ( pressed == PB_UP ) {
604 | delay_ms (200) ;
605 | entered_ph_max += 0.1;
606 | if ( entered_ph_max > 14.0) {
607 | entered_ph_max = 8.0;
608 | }
609 | } else if ( pressed == PB_DOWN ) {
610 | delay_ms (200) ;
611 | entered_ph_max -= 0.1;
612 | if ( entered_ph_max < 0.0) {
613 | entered_ph_max = 0.0;
614 | }
615 | } else if ( pressed == PB_OK ) {
616 | delay_ms (200) ;
617 | phMaxValue = entered_ph_max ;
618 | break ;
619 | } else if ( pressed == PB_cancel ) {
620 | delay_ms (200) ;
621 | break ;
622 | }
623 | }
624 | }

625
626 // set desired range for tds values

627 | void set_tds_range () {
628 | int entered_tds_min = 300;
629 | while ( true ) {
630 | lcd_clear () ;
631 | lcd_setCursor (0 ,0) ;
632 | lcd_write () ;
633 | " TDS Min : " + String ( entered_tds_min )
634 | int pressed = wait_for_button_press () ;

635
636 | if ( pressed == PB_UP ) {
637 | delay_ms (200) ;
638 | entered_tds_min += 10;
639 | if ( entered_tds_min > 2000) {
640 | entered_tds_min = 300;
641 | }
642 | } else if ( pressed == PB_DOWN ) {
643 | delay_ms (200) ;
644 | entered_tds_min -= 10;
645 | if ( entered_tds_min < 0) {
646 | entered_tds_min = 0;
647 | }
648 | } else if ( pressed == PB_OK ) {
649 | delay_ms (200) ;
650 | tdsMinValue = entered_tds_min ;
651 | break ;
652 | } else if ( pressed == PB_cancel ) {
653 | delay_ms (200) ;
654 | break ;
655 | }
656 | }

657
658 | int entered_tds_max = 1000;
659 | while ( true ) {
660 | lcd_clear () ;
661 | lcd_setCursor (0 ,0) ;
662 | lcd_write ("TDS Max : " + String ( entered_tds_max ));

663
664 | int pressed = wait_for_button_press () ;

665
666 | if ( pressed == PB_UP ) {
667 | delay_ms (200) ;
668 | entered_tds_max += 10;
669 | if ( entered_tds_max > 2000) {
670 | entered_tds_max = 1000;
671 | }
672 | } else if ( pressed == PB_DOWN ) {
673 | delay_ms (200) ;
674 | entered_tds_max -= 10;
675 | if ( entered_tds_max < 0) {
676 | entered_tds_max = 0;
677 | }
678 | } else if ( pressed == PB_OK ) {
679 | delay_ms (200) ;
680 | tdsMaxValue = entered_tds_max ;
681 | break ;
682 | } else if ( pressed == PB_cancel ) {
683 | delay_ms (200) ;
684 | break ;
685 | }
686 | }
687 | }

688
689 | // Execute the selected mode
690 | void run_mode ( int mode ) {
691 | if ( mode == 0) {
692 | set_temp_range () ; | // Set temperature range
693 | } else if ( mode == 1) {
694 | set_ph_range () ; | // Set pH range
695 | } else if ( mode == 2) {
696 | set_tds_range () ; | // Set TDS range
697 | } else if ( mode == 3) {
698 | set_motor_activation_time () ; | // Set motor activation time
699 | } else if ( mode == 4) {

700 | set_motor_duration () ; | // Set motor duration
701 | } else if ( mode == 5) {
702 | int x = 1; | // Placeholder for future functionalities
703 | }
704 | }

705

706

707
708 | // Function to initialize ADC
709 | void adc_init () {
710 | ADMUX = (1 << REFS0 ); // Reference voltage set to AVcc
711 | ADCSRA = (1 << ADEN ) | (1 << ADPS2 ) | (1 << ADPS1 ); // Enable ADC and set prescaler
to 64

712 }

713
714 | // Function to read ADC value
715 | uint16_t adc_read ( uint8_t channel ) {
716 | ADMUX = ( ADMUX & 0 xF0 ) | ( channel & 0 x0F ); // Select the corresponding channel 0~7
717 | ADCSRA |= (1 << ADSC ); // Start conversion
718 | while ( ADCSRA & (1 << ADSC )); // Wait for conversion to complete
719 | return ADC ;
720 | }

721
722 | // Function to check sensor readings and trigger alarms if out of range
723 | void check_sensors () {
724 | // Read temperature from DS18B20 sensor
725 | float temperatureC = DS18B20_ReadTemperature ( TempSensorPin );

726
727 | // Check if temperature is above the high threshold
728 | if ( temperatureC > h_temp ) {
729 | lcd_setCursor (0 , 40) ;
730 | lcd_write (" TEMP HIGH ");
731 | ring_alarm () ;
732 | delay_ms (200) ;
733 | }
734 | // Check if temperature is below the low threshold
735 | else if ( temperatureC < l_temp ) {
736 | lcd_setCursor (0 , 40) ;
737 | lcd_write (" TEMP LOW ");
738 | ring_alarm () ;
739 | delay_ms (200) ;
740 | }

741
742 | // Read pH value from ADC and convert to pH units
743 | uint16_t rawPhValue = adc_read ( PhSensorPin );
744 | float phValue = ( float ) rawPhValue * 5.0 / 1024.0;
745 | phValue = 3.5 * phValue + phCalibrationValue ;

746
747 | // Check if pH is out of the defined range
748 | if ( phValue > phMaxValue || phValue < phMinValue ) {
749 | lcd_setCursor (0 , 50) ;
750 | lcd_write ("pH OUT OF RANGE ");
751 | ring_alarm () ;
752 | delay_ms (200) ;
753 | }

754
755 | // Read TDS value from ADC and process the buffer
756 | uint16_t rawTdsValue = adc_read ( TdsSensorPin );
757 | tdsAnalogBuffer [ tdsAnalogBufferIndex ] = rawTdsValue ;
758 | tdsAnalogBufferIndex ++;
759 | if ( tdsAnalogBufferIndex == SCOUNT ) {
760 | tdsAnalogBufferIndex = 0;
761 | tdsAverageVoltage = 0;
762 | for (int i = 0; i < SCOUNT ; i ++) {
763 | tdsAverageVoltage += tdsAnalogBuffer [i ];
764 | }
765 | tdsAverageVoltage /= SCOUNT ;
766 | float tdsVoltage = tdsAverageVoltage * 5.0 / 1024.0;
767 | float tdsValue = (133.42 * pow ( tdsVoltage / VREF , 3) - 255.86 * pow ( tdsVoltage /
VREF , 2) + 857.39 * ( tdsVoltage / VREF )) * 0.5;

768
769 | // Check if T

770

771
772 | // function to ring the buzzer
773 | void ring_alarm () {
774 | bool break_happened = false ;
775 | while ( should_ring_alarm && ( PINB & (1 < < PB3 )) ) {
776 | for (int i = 0; i < n_notes ; i ++) {
777 | if (!( PINB & (1 < < PB3 ) )) {
778 | delay_ms (200) ;
779 | should_ring_alarm = false ; | // Set flag to false
780 | break_happened = true ;
781 | // Turn off the buzzer
782 | TCCR0A &= ~(1 << COM0A0 ); | // Disable output
783 | break ;
784 | }
785 | // Generate tone
786 | int period = 16000000 / notes [i ]; | // Calculate the period
787 | OCR0A = period / 2; | // Set the output compare register
788 | TCCR0A = (1 << WGM01 ) | (1 << COM0A0 ); | // Set the timer mode and output mode
789 | TCCR0B = (1 << CS01 ) | (1 << CS00 ); | // Set the prescaler
790 | DDRB |= (1 << PB3 ); | // Set PB3 as output

791
792 | delay_ms (500) ;

793
794 | // Turn off the buzzer
795 | TCCR0A &= ~(1 << COM0A0 ); | // Disable output
796 | delay_ms (2) ;
797 | }
798 | }

799
800 | // Add a delay_ms after the loop to prevent immediate restart
801 | delay_ms (1000) ;
802 | }

Listing 1: The Main Code

### 1.13.2 uart library code

For developing this code we obsereved the data sheet of ATmega328PU Microcontroller.
In the library code we manipulated the
1. UCSR0C Register: The UCSR0C register (USART Control and Status Register C) is part of the USART (Universal Synchronous and Asynchronous serial Receiver and Transmitter) control registers in the ATmega328P microcontroller. This register is used to configure the characteristics of the USART communication, such as the mode of operation, parity bit setting, stop bit setting, and data frame size.
- UMSEL01, UMSEL00 (USART Mode Select):

– 00: Asynchronous USART
– 01: Synchronous USART
- UPM01, UPM00 (Parity Mode):

– 00: Disabled (No Parity)
- UCSZ02, UCSZ01, UCSZ00 (Character Size):

– 011: 8-bit data

2. UCSR0B Register: This register is where the RXEN0 and TXEN0 pins are used to enable and disable the transmitter (TX) and receiver (RX).
3. UCSR0A Register: This register includes the U2X0 bit, which is used to select double speed or normal speed mode for USART communication.
- 0: Normal speed
- 1: Double speed
4. UDR0 Register: This register holds the data that is received and the data that is ready to be transmitted.

5. UBRR0 Register: This register is used to set the baud rate for the USART communication.

1 // UART Transmission

2

3
4 | // receive one byte data
5 | // It waits until the receive buffer is full by checking the RXC0 bit in the UCSRA
register . Once data is available , it returns the data from the UART Data Register ( UDR0 ).
6 | unsigned char USART_Receive ()
7 | {
8 | while (!( UCSR0A & (1 < < RXC0 ))); | // checks recieve buffer
9 | return UDR0 ; // returns the data from the UART Data Register
10 | }

11

12
13 | // transmit one byte
14 | //t waits until the transmit buffer is empty by checking the UDRE0 bit in the UCSRA
register . Then it loads the character ch into the UART Data Register ( UDR0 ) for transmission .
15 | void UART_Txchar ( char ch )
16 | {
17 | while (!( UCSR0A & (1 < < UDRE0 ))); // WAIT UNTIL EMPTY TRANSMIT BUFFER
18 | UDR0 = ch ; // after transmit buffer empty load data to the uart data register

19
20 }

21

22
23 | // transmit string through UART
24 | // It calculates the length of the string and transmits each character in the string one
by one using the UART_Txchar function .
25 | void trans_string ( char str []) {
26 | int lenght = strlen ( str ) ;
27 | char trans ;
28 | for ( int i =0; i < lenght ;i ++) {
29 | trans = str [i ];
30 | UART_Txchar ( trans ) ;
31 | }
32 | }

33
34 | // transmit number
35 | // It converts the number to a string , calculates the length of the string , and
transmits each character in the string one by one using the UART_Txchar function .
36 | void trans_num ( uint16_t num ){
37 | String number = String ( num );
38 | int lenght = number . length () ;
39 | char trans ;
40 | for ( int i =0; i < lenght ;i ++) {
41 | trans = number [i ];
42 | UART_Txchar ( trans ) ;
43 | }
44 | // UART_Txchar ( ’\n ’);
45 | }

46
47 | void init_uart () {
48 | // Enable transmitter and recirever bits - Use USART0

49
50 | UCSR0B |= (1 < < RXEN0 ) | (1 < < TXEN0 ); // ENABLE TX AND RX

51
52 | // SET THE DATA SIZE FOR COMMUNIATION
53 | UCSR0C &= (~(1 < < UMSEL00 )) & (~(1 < < UMSEL01 )); | // ENABLE ASYNCHRONOUS USART
COMMUNICATION BY CLEARING UMSEL00 and UMSEL01 bits in the UCSR0C register
54 | UCSR0C &= (~(1 < < UPM00 )) & (~(1 < < UPM01 )) ; | // DISABLE PARITY BIT BY CLEARING UPM00 AND
UPM01 BITS IN THE USR0C REGISTER
55 | UCSR0C &= (~(1 < < USBS0 )) ; // CHOOSE ONE STOP BIT BY CLEARING USBS0 BIT

56
57 | // SET DATA LENGTH TO BE 8 BITS
58 | UCSR0B &= (~(1 < < UCSZ02 ) );
59 | UCSR0C |= (1 < < UCSZ00 ) | (1 < < UCSZ01 ); | // SET 8 BITS 011 BITS IN UCSZ02 , UCSZ00 , UCSZ01

60
61 | // SET THE SPEED FOR TRANSMISSION
62 | UCSR0A |= (1 < < U2X0 ) ; // SELSCT HIGH SPEED MODE SETTING U2X0 bit in the UCSR0A register
to select high - speed mode .

63 | // UCSR0A &= ~(1 < < U2X0 ); // low speed

64
65 | // BAUDRATE
66 | UBRR0 = 207; // SETS UBRR0 REGISTER TO 207 TO GET BAUDRATE OF 9600//9600 BAUDRATE FROM
| 16 MHz cpu clock rate ( U2X0 bit is set ( double speed mode ))
67 | }

Listing 2: uart.cpp file

1 | # ifndef UART_H
2 | # define UART_H

3
4 | unsigned char USART_Receive () ;
5 | void UART_Txchar ( char ch );
6 | void trans_string ( char str []) ;
7 | void trans_num ( uint16_t num );
8 | void init_uart () ;

9
10 # endif
Listing 3: uart.h file

### 1.13.3 delay library code

The delay ms function creates a delay by configuring Timer1 in CTC mode with a prescaler of 64. It sets the compare match register to 249, which corresponds to a delay of 1 millisecond. The function loops for the specified number of milliseconds (ms), generating a precise delay by waiting for the timer to reach the compare match value and then clearing the flag to reset the timer. The following are the registers we manipulated:

1. TCCR1A:
- Configures the behavior of Timer1.
- In the function, it is cleared to 0 to start with a known state.
2. TCCR1B:
- Sets the mode of operation and clock prescaler for Timer1.
- Configured to CTC mode with a prescaler of 64.
3. TCNT1:
- Holds the current value of Timer1.
- Reset to 0 to start counting from zero.
4. OCR1A:
- Sets the compare match value for Timer1.
- Configured to 249 for a 1ms delay.
5. TIFR1:
- Contains flags for Timer1 events.
- The OCF1A flag indicates when Timer1 reaches the compare match value and is cleared after each iteration.

1 // delay function

2
3 // This loop iterates ms times , creating a delay of ms milliseconds by generating a delay of 1 millisecond in each iteration .
4 | void delay_ms ( unsigned int ms ) {
5 | for ( unsigned int i = 0; i < ms ; i ++) {
6 | // These lines reset the Timer1 control registers and counter to ensure Timer1 is
in a known state before configuring it.
7 | TCCR1A = 0; | // Clear Timer1 Control Register A

8 | TCCR1B = 0; | // Clear Timer1 Control Register B
9 | TCNT1 = 0; | // Clear Timer1 Counter

10
11 | // | sets Timer1 to CTC ( Clear Timer on Compare Match ) mode by setting the WGM12
bit in the TCCR1B register . It also sets the prescaler to 64 by setting the CS11 and CS10 bits .
12 | TCCR1B |= (1 << WGM12 ) | (1 << CS11 ) | (1 << CS10 );

13
14 | // Set compare match register for 1ms delay
15 | OCR1A = 249;

16
17 | // waits until the Output Compare Flag A ( OCF1A ) in the Timer / Counter Interrupt
Flag Register ( TIFR1 ) is set , indicating that the timer has reached the value in OCR1A
18 | while (!( TIFR1 & (1 << OCF1A )) );

19
20 | // clears the compare match flag by writing a 1 to the OCF1A bit in the TIFR1
register . This is necessary to reset the flag so that it can be used again in the next iteration of the loop .
21 | TIFR1 |= (1 << OCF1A );
22 | }
23 | }

Listing 4: delay.cpp file

1 | # ifndef DELAY_H
2 | # define DELAY_H

3
4 void delay_ms ( unsigned int ms ) ;

5
6 # endif
Listing 5: delay.h file

### 1.13.4 SoftwareSerial library code

1 | /**
2 | * --- ----- ----- ---- ----- ----- ---- ----- ----- ---- ----- ---- ----- ----- ---- ----- ----- ---- ---+
3 | * @desc SoftwareSerial .h library
4 | * --- ----- ----- ---- ----- ----- ---- ----- ----- ---- ----- ---- ----- ----- ---- ----- ----- ---- ---+
5 | * @source
6 | * | Copyright 2020 Florean Shweiger
7 | * Written by Florean Shweiger

8
9 | * Modified by Nipuni Herath
10 | * Date : 2024/07/20
11 | * Description : Edited for specific project requirements
12 | */

13

14
15 | // Define the serial pins for communication with the ESP -01 module
16 | // # define ESP_TX 2
17 | // # define ESP_RX 3

18
19 | // SoftwareSerial espSerial ( ESP_TX , ESP_RX ); | // add baud rate as well
20 | **********************************************************************
21 | # define SOFTWARE_SERIAL_BUFFER_SIZE 64 // Define buffer size ( change if needed )
22 | // Define a buffer for incoming data
23 | static uint8_t rxBuffer [ SOFTWARE_SERIAL_BUFFER_SIZE ];
24 | static volatile uint8_t rxBufferHead = 0;
25 | static volatile uint8_t rxBufferTail = 0;
26 | static uint8_t txPin ;
27 | static uint8_t rxPin ;
28 | static uint16_t txDelay ;

29
30 | // Initialize SoftwareSerial with a specific baud rate
31 | // keep
32 | void SoftwareSerial_Init ( uint8_t receivePin , uint8_t transmitPin , uint32_t baudRate ) {
33 | rxPin = receivePin ;
34 | txPin = transmitPin ;

// Set the transmit pin as output
DDRB |= (1 << txPin ) ;
PORTB |= (1 << txPin ); // Set high to idle state

// Set the receive pin as input with a pull -up resistor DDRB &= ~(1 << rxPin );
PORTB |= (1 << rxPin ); // Enable pull -up resistor

// Calculate timing parameters for the baud rate uint16_t bitDelay = ( F_CPU / baudRate ) / 4; txDelay = bitDelay - (15 / 4) ;

// Initialize the receive interrupt
49 | PCICR |= (1 << PCIE0 ); | // Enable pin change interrupts for PCINT [7:0]
50 | PCMSK0 |= (1 << rxPin ); | // Enable pin change interrupt for receive pin

}

// End SoftwareSerial communication void SoftwareSerial_End () {
// Disable the receive interrupt PCMSK0 &= ~(1 << rxPin );
PCICR &= ~(1 << PCIE0 );

}

// Read data from the buffer
int SoftwareSerial_Read () {
if ( rxBufferHead == rxBufferTail ) { return -1; // Buffer empty

}

uint8_t data = rxBuffer [ rxBufferHead ];
rxBufferHead = ( rxBufferHead + 1) % SOFTWARE_SERIAL_BUFFER_SIZE ; return data ;

}

// Check if data is available in the buffer
int SoftwareSerial_Available () {
return ( SOFTWARE_SERIAL_BUFFER_SIZE + rxBufferTail - rxBufferHead ) % SOFTWARE_SERIAL_BUFFER_SIZE ;

}

// Write data to the transmit buffer
void SoftwareSerial_Write ( uint8_t data ) { // Wait until the transmit line is idle
while ( PINB & (1 << txPin ) ) {
_delay_us ( txDelay ); // Delay for bit timing

}

// Start bit
PORTB &= ~(1 << txPin );
_delay_us ( txDelay );

// Send each bit
for ( uint8_t i = 0; i < 8; ++ i) { if ( data & (1 << i )) {
PORTB |= (1 << txPin );
} else {
PORTB &= ~(1 << txPin ) ;

}
_delay_us ( txDelay );

}

// Stop bit
PORTB |= (1 << txPin );
_delay_us ( txDelay );

}

Listing 6: SoftwareSerial.cpp file

# ifndef SOFTWARE_SERIAL_H

2 # define SOFTWARE_SERIAL_H

3
4 # include < stdint .h >

5
6 | // Define buffer size
7 | # define SOFTWARE_SERIAL_BUFFER_SIZE 64

8
9 | // Initialize SoftwareSerial with a specific baud rate
10 | void SoftwareSerial_Init ( uint8_t receivePin , uint8_t transmitPin , uint32_t baudRate );

11
12 | // End SoftwareSerial communication
13 | void SoftwareSerial_End () ;

14
15 | // Read data from the buffer
16 | int SoftwareSerial_Read () ;

17
18 | // Check if data is available in the buffer
19 | int SoftwareSerial_Available () ;

20
21 | // Write data to the transmit buffer
22 | void SoftwareSerial_Write ( uint8_t data );

23
24 # endif // SOFTWARE_SERIAL_H

Listing 7: SoftwareSerial.h file
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

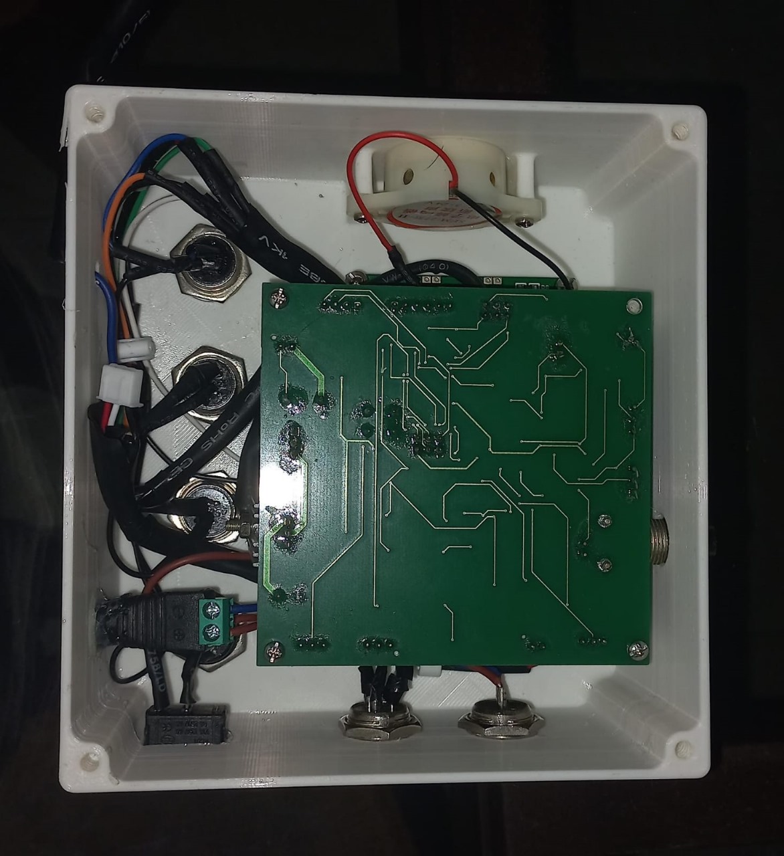
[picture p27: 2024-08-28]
Images/system integration part 1.jpeg

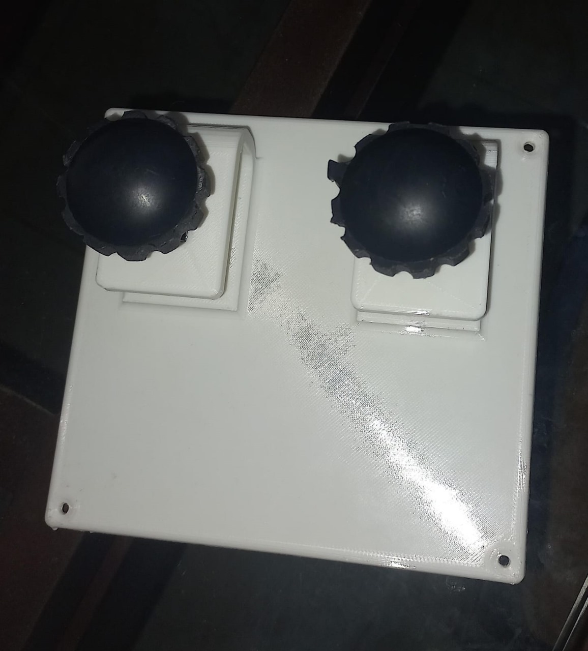
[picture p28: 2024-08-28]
Images/user interface lid.jpeg

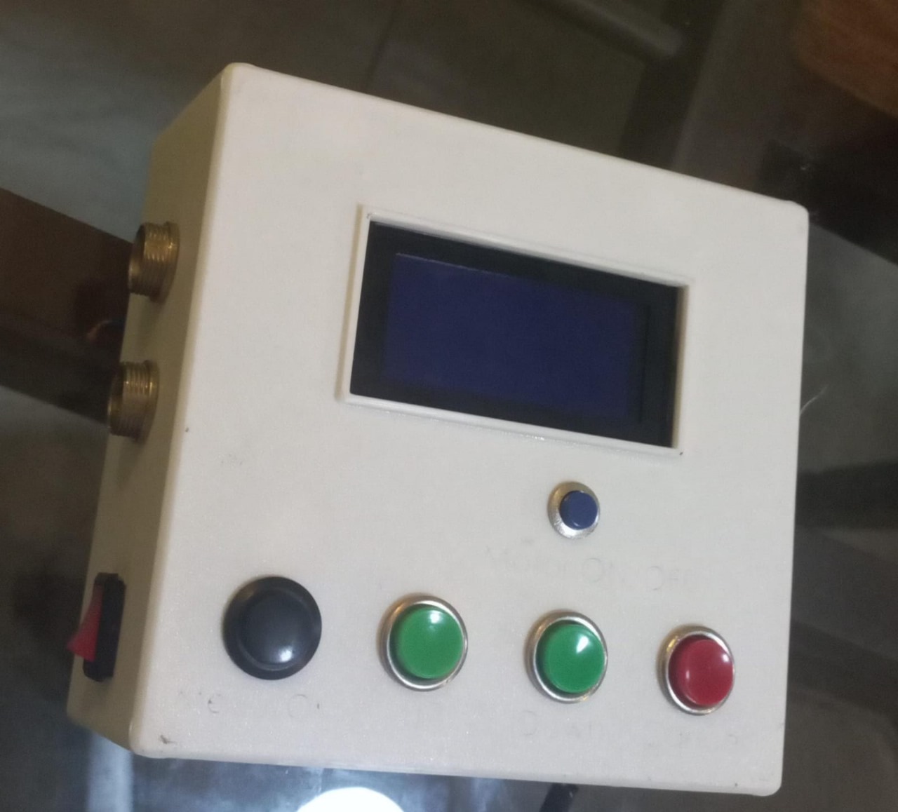
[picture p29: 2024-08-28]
Images/user interface box.jpeg

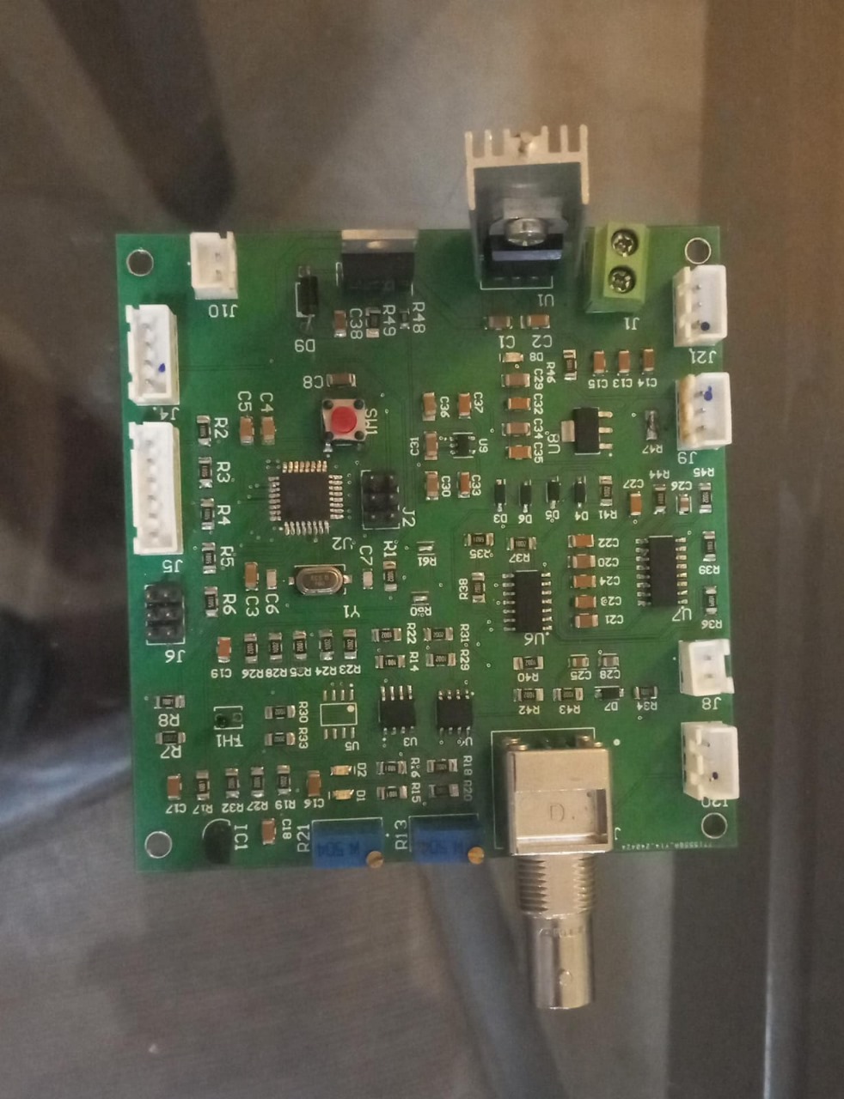
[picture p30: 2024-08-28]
Images/PCB.jpeg

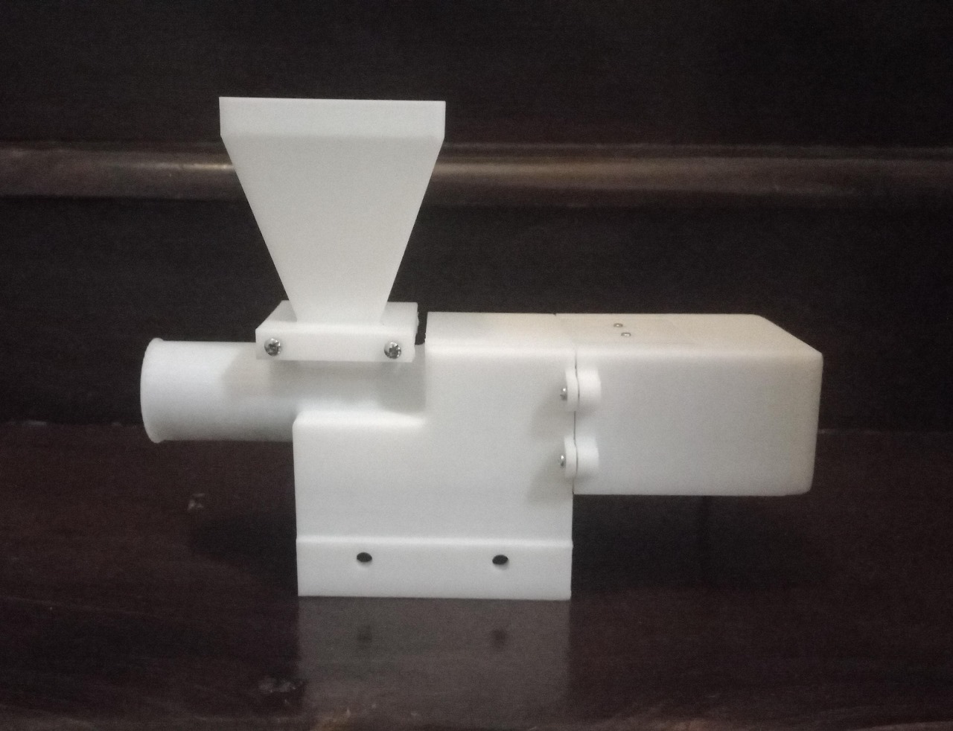
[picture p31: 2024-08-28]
Images/feeder.jpeg

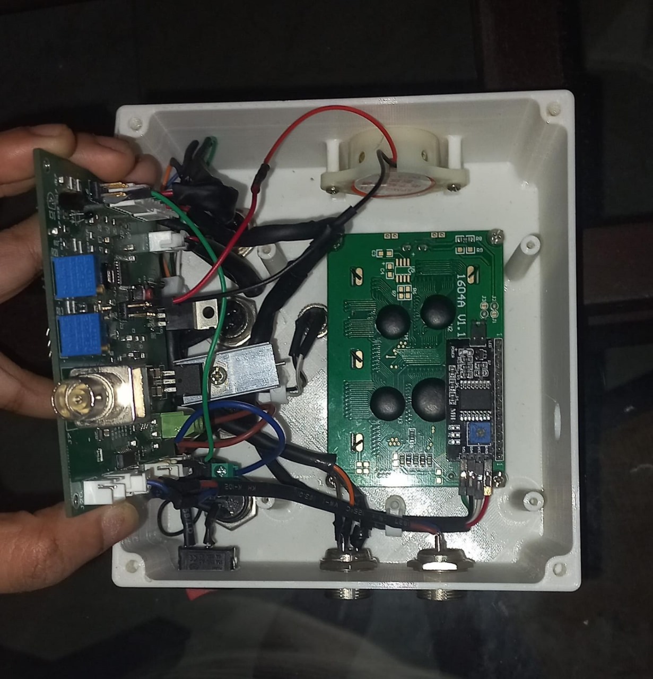
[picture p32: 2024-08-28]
Images/system integration part 2.jpeg

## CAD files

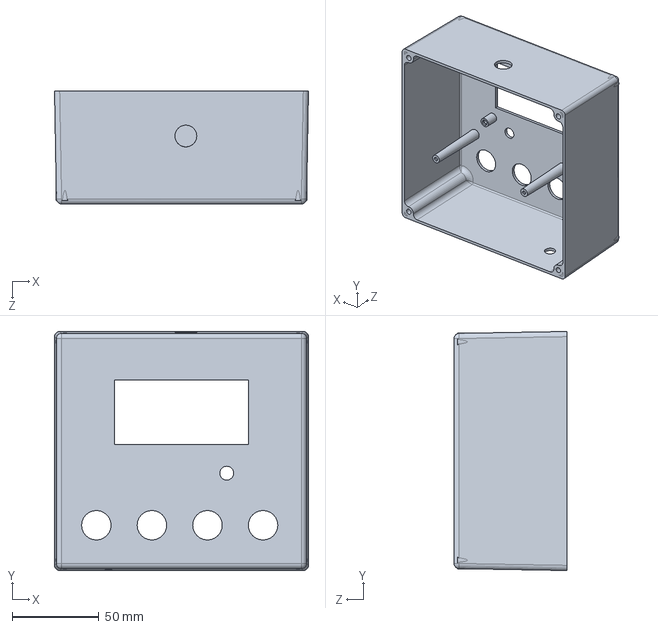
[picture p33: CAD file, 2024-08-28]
Enclosure designs (SolidWorks)/Solid Modeling - User Interface/User Interface Box - Final Design.SLDPRT
146.2 x 137.7 x 65.0 mm

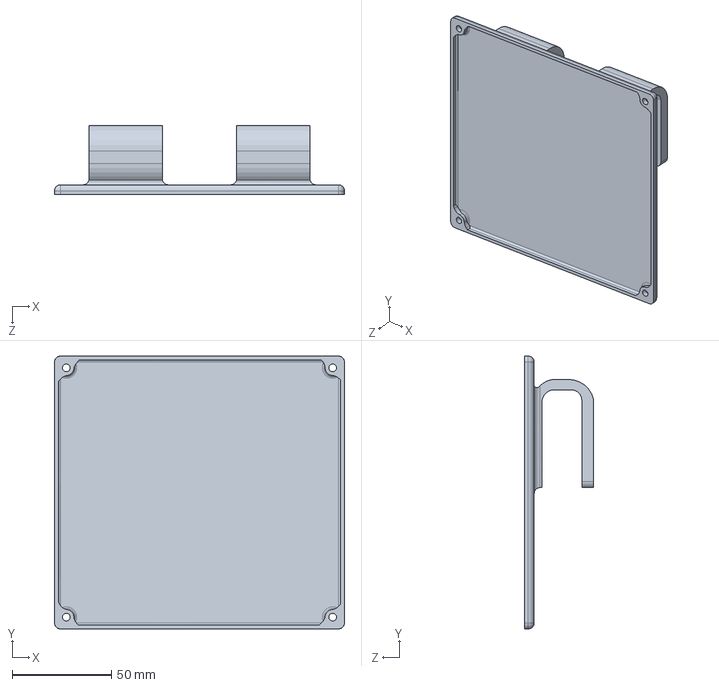
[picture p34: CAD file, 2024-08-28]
Enclosure designs (SolidWorks)/Solid Modeling - User Interface/User Interface Lid - Final Design.SLDPRT
146.2 x 137.6 x 35.0 mm

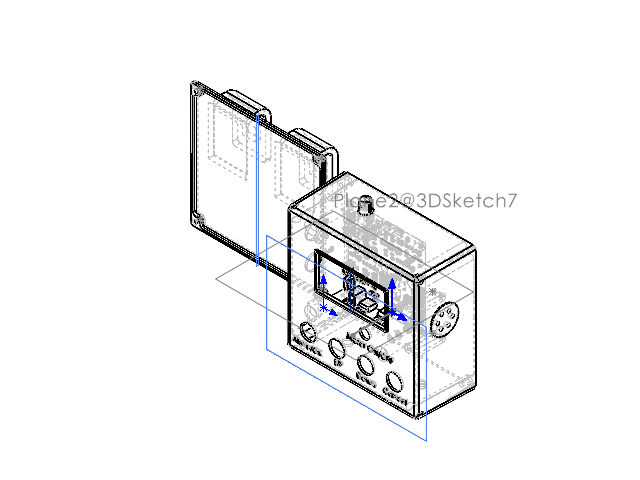
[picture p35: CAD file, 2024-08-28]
Enclosure designs (SolidWorks)/Solid Modeling - User Interface/User Interface Assembly.SLDASM
user interface box final
PCB1-1
user interface lid

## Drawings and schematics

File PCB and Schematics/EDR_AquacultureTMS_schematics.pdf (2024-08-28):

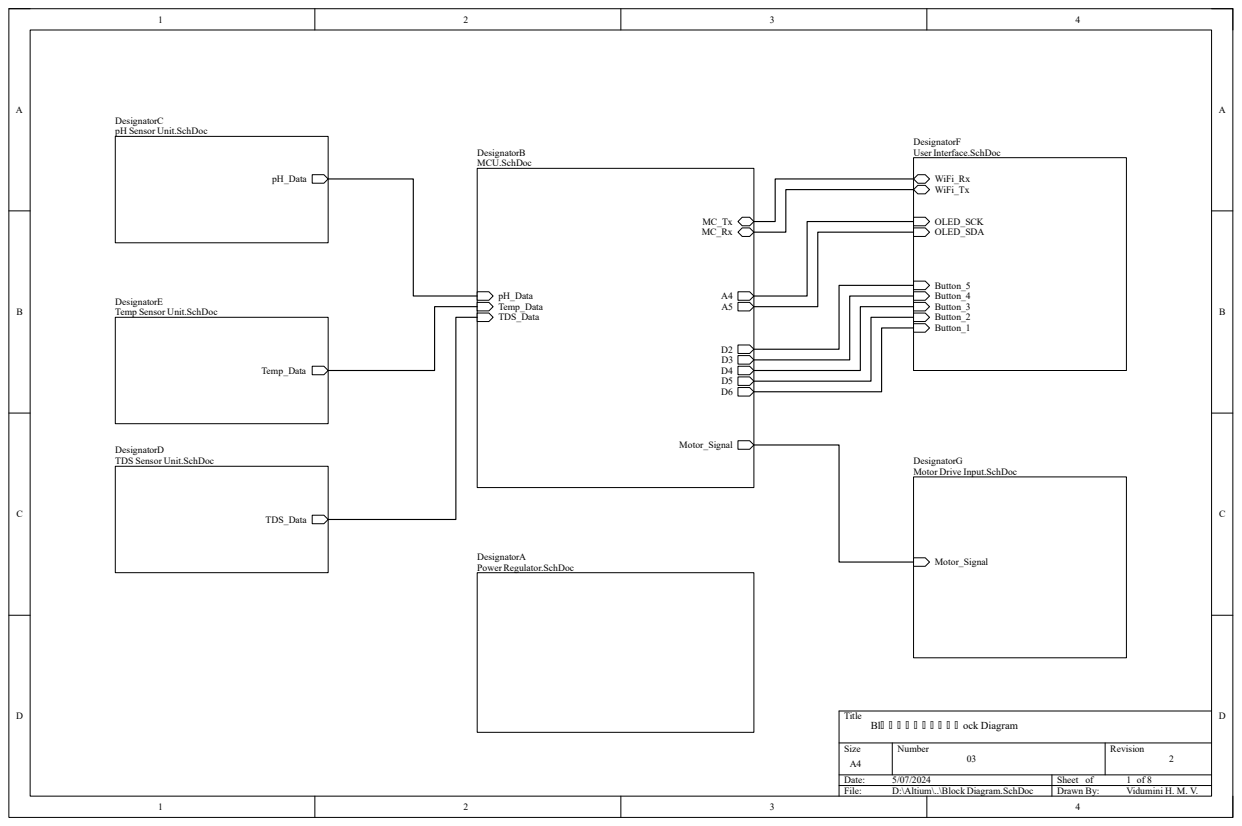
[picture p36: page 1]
Title; Size; Number; Revision; Date:; Sheet of; File:; D:\Altium\..\Block Diagram.SchDoc; Drawn By:; pH_Data Temp_Data TDS_Data; Motor_Signal; DesignatorB MCU.SchDoc; pH_Data; TDS_Data; Temp_Data; WiFi_Rx WiFi_Tx; OLED_SCK OLED_SDA; Button_5 Button_4 Button_3 Button_2 Button_1; ock Diagram; Vidumini H. M. V.

DesignatorC
pH Sensor Unit.SchDoc

DesignatorF
User Interface.SchDoc

DesignatorE
Temp Sensor Unit.SchDoc

DesignatorD
TDS Sensor Unit.SchDoc

DesignatorG
Motor Drive Input.SchDoc

DesignatorA
Power Regulator.SchDoc

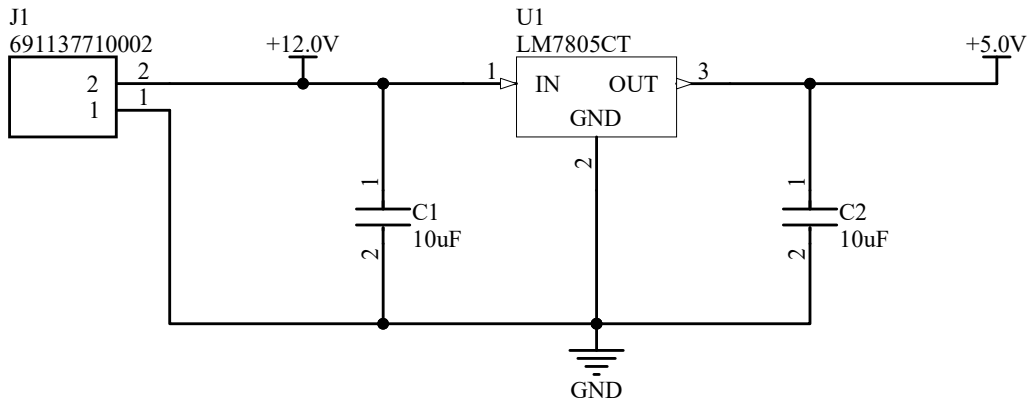
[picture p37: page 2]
Size; Number; Revision; Date:; Sheet of; File:; D:\Altium\..\Power Regulator.SchDoc; Drawn By:; Vidumini H. M. V.; OUT; GND

Title
Power Regulator Circuit

+5.0V1 2

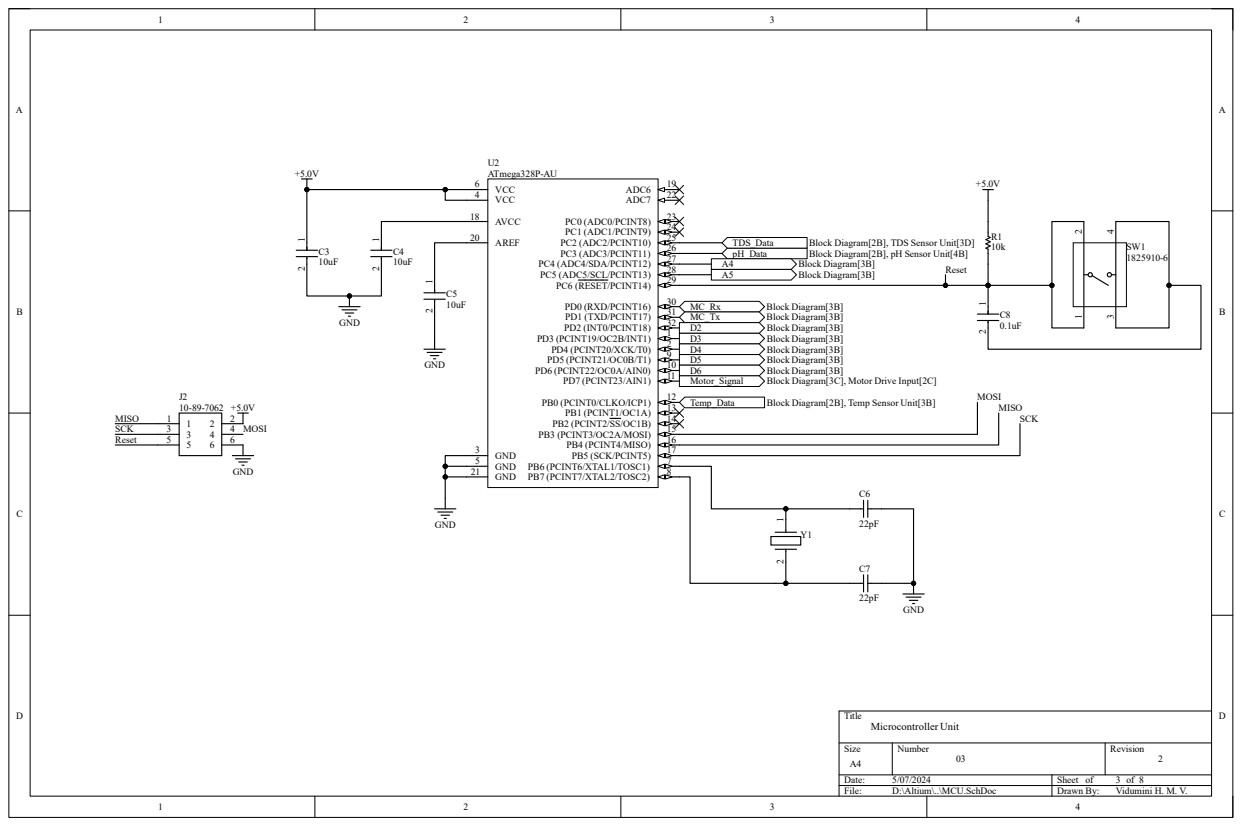
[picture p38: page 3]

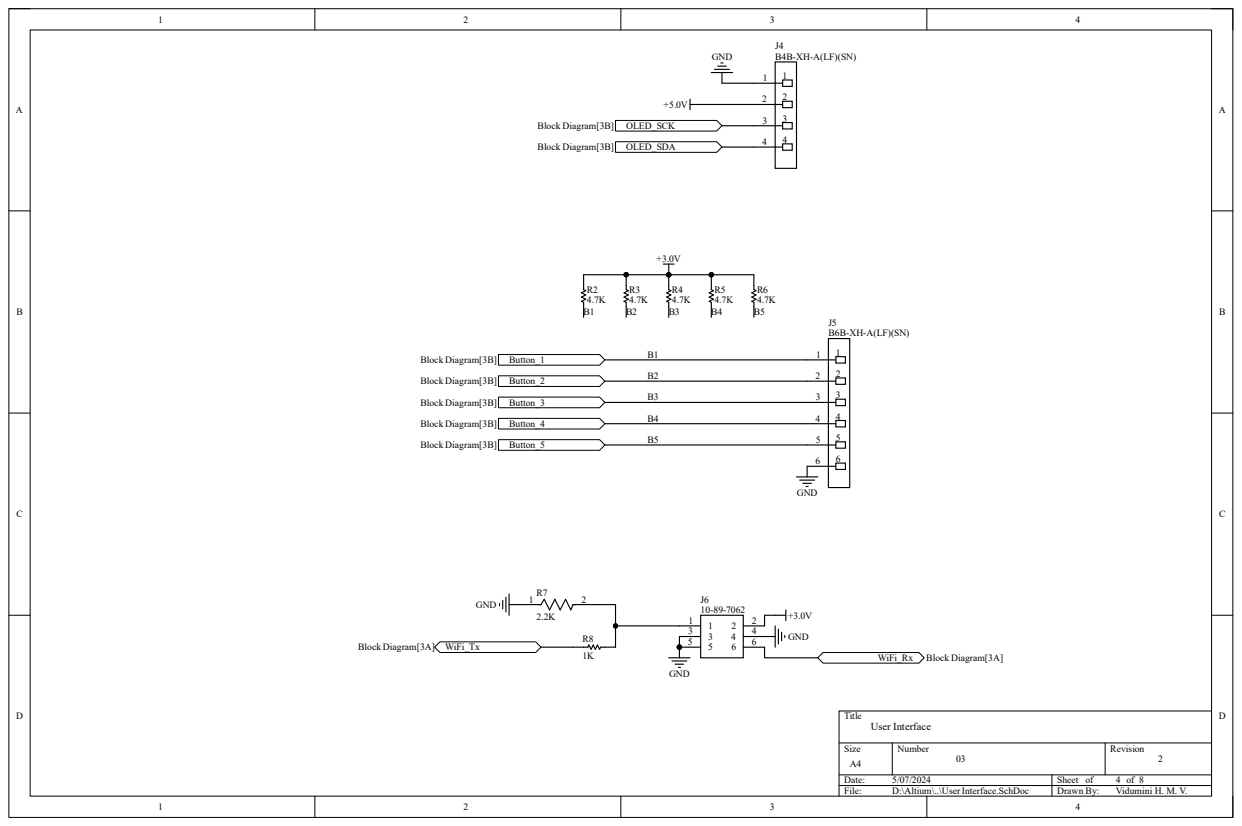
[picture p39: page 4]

1K 1 2

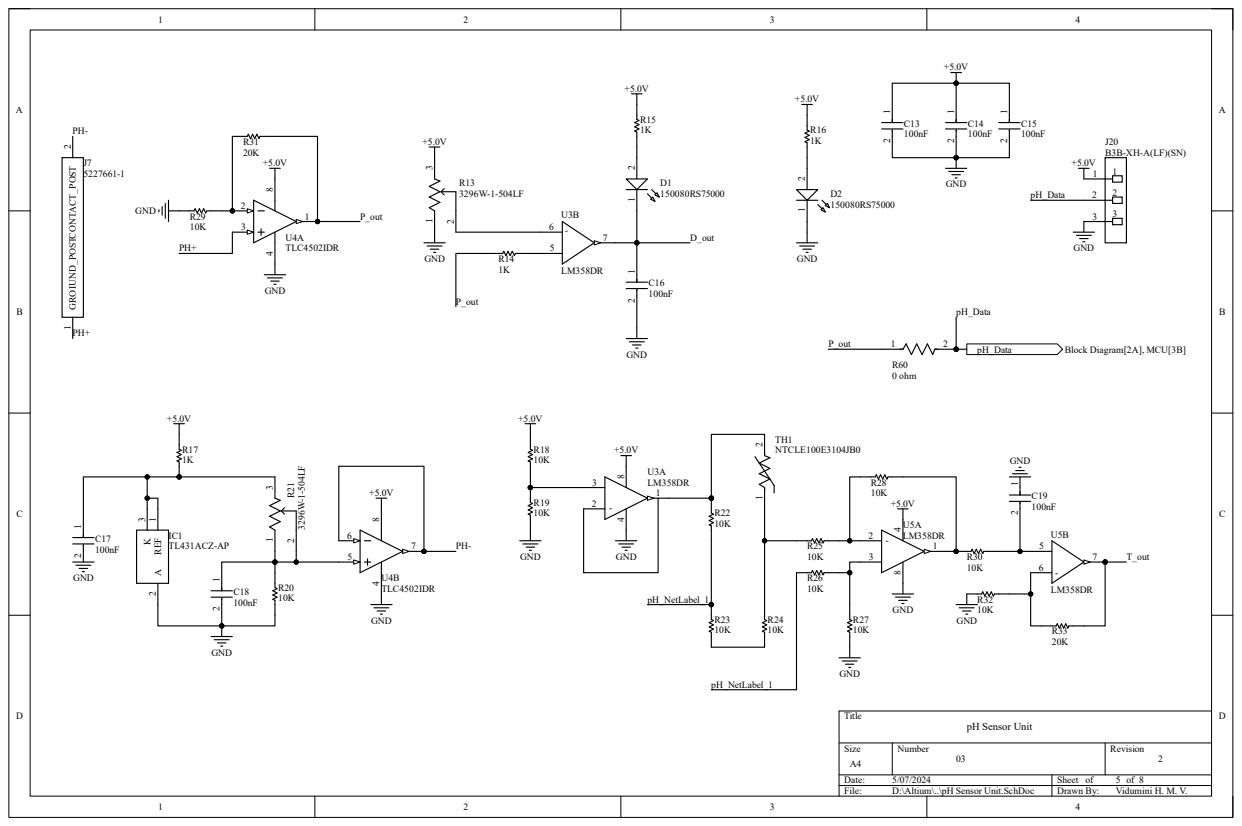
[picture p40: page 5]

100nF 1 2

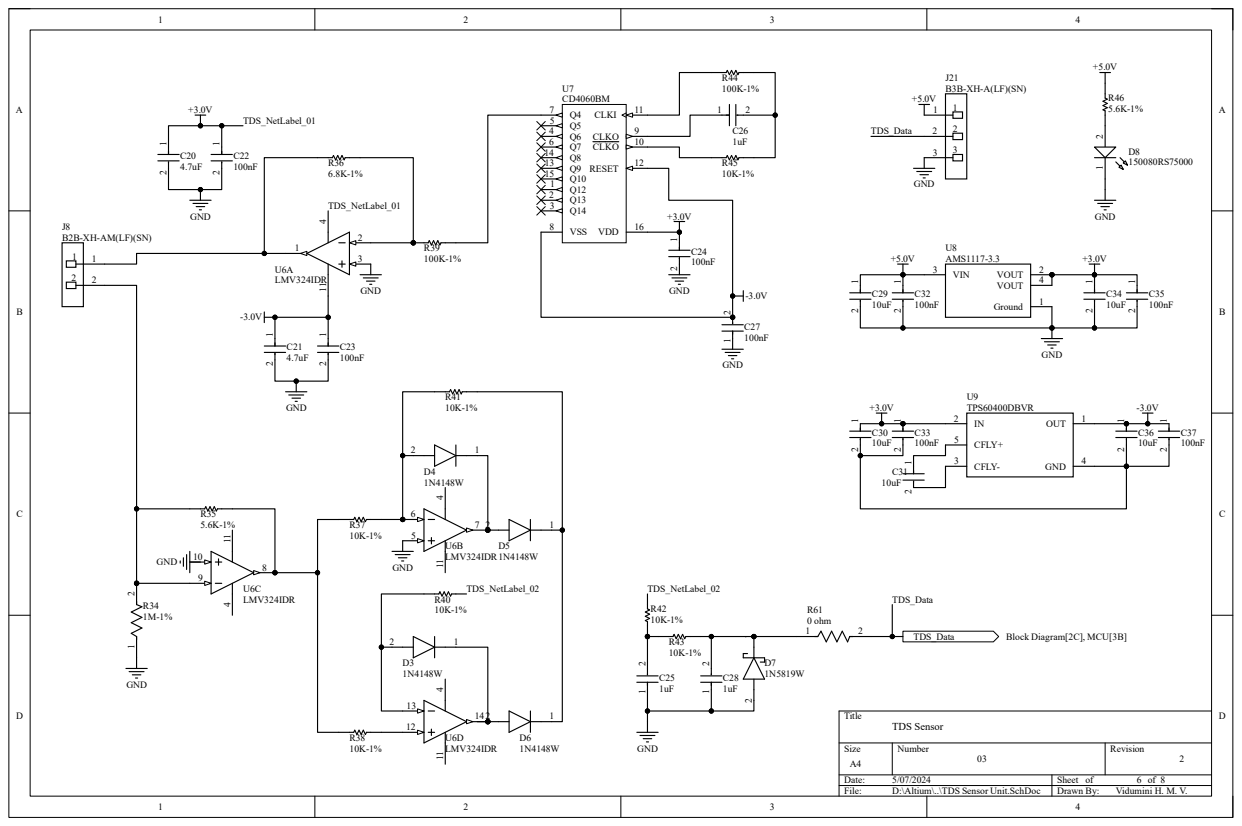
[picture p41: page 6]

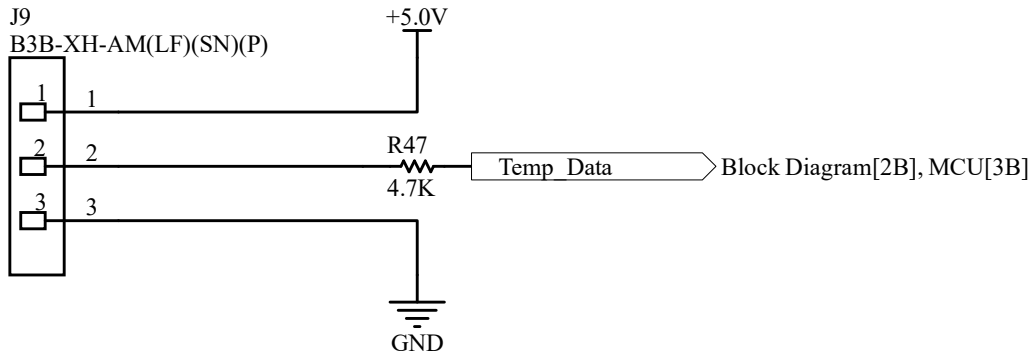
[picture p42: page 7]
Title; Size; Number; Revision; Date:; Sheet of; File:; D:\Altium\..\Temp Sensor Unit.SchDoc; Drawn By:; GND; Temp_Data; Block Diagram[2B], MCU[3B]; Vidumini H. M. V.

Temperature Sensor Unit

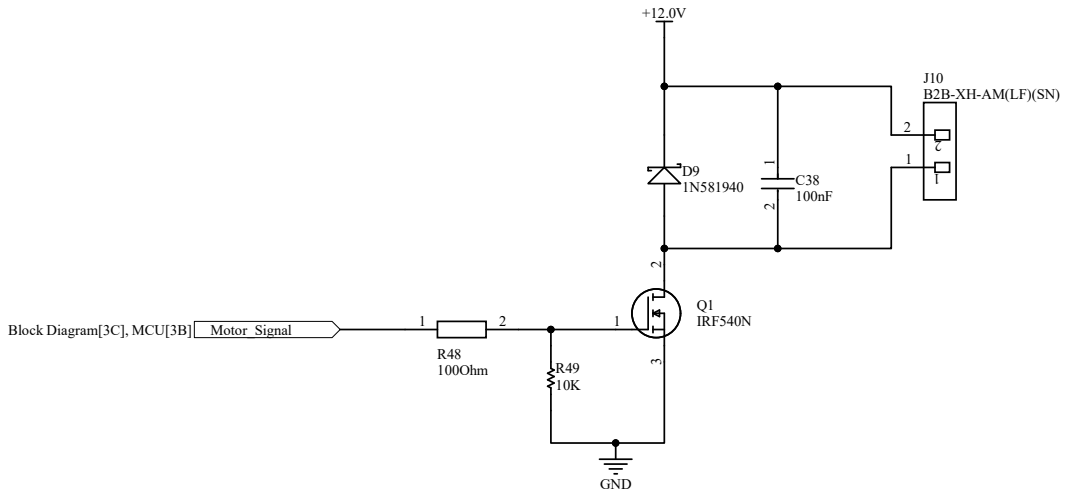
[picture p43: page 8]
Title; Size; Number; Revision; Date:; Sheet of; File:; D:\Altium\..\Motor Drive Input.SchDoc; Drawn By:; IRF540N; 100Ohm; GND; Motor Drive; Vidumini H. M. V.

Block Diagram[3C], MCU[3B] Motor_Signal

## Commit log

2024-08-28 Create Functions needed for I2C communication and LCD display
2024-08-28 Create Functions needed for Dallas temperature sensor operations
